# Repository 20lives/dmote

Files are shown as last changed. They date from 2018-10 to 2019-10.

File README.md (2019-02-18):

## The Dactyl-ManuForm keyboard: Opposable Thumb Edition

This, the DMOTE, is a fork of the
[Dactyl-ManuForm](https://github.com/tshort/dactyl-keyboard), a parametrized,
split-hand, concave, columnar, ergonomic keyboard. In this fork, the thumb
cluster has been modified to minimize shearing forces.

Image of the second working DMOTE (http://viktor.eikman.se/article/the-dmote/)

Parameters have been moved out of the application code itself, into separate
files that are safe and easy to edit. Use them to change:

- Switch type: ALPS or MX.
- Size and shape.
    - Row and column curvature and tilt (tenting).
    - Exceptions at any level, down to the position of individual keys.
- Minor features like LED strips and wrist rests.

For documentation see [doc/](doc/).

### License

Copyright © 2015-2019 Matthew Adereth, Tom Short, Viktor Eikman et al.

The source code for generating the models (everything excluding the [things/](things/) and [resources/](resources/) directories) is distributed under the [GNU AFFERO GENERAL PUBLIC LICENSE Version 3](LICENSE). The generated models and PCB designs are distributed under the [Creative Commons Attribution-NonCommercial-ShareAlike License Version 3.0](LICENSE-models).

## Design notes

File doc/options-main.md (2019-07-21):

# General configuration options

Each heading in this document represents a recognized configuration key in the main body of a YAML file for a DMOTE variant. Other documents cover special sections of this one in more detail.

## Parameter `split`

If `true`, build two versions of the case: One for the right hand and a mirror image for the left hand. Threaded holes and other chiral components of the case are exempted from mirroring.

## Section `keys`

Keys, that is keycaps and electrical switches, are not the main focus of this application, but they influence the shape of the case.

### Parameter `preview`

If `true`, include models of the keycaps in place on the keyboard. This is intended for illustration as you work on a design, not for printing.

### Parameter `styles`

Here you name all the types of keys on the keyboard. For each type, describe the properties of the style using the parameters of the [`dmote-keycap`](https://github.com/veikman/dmote-keycap) library, documented in that project. The names of the styles are then used elsewhere, as described [here](options-nested.md).

Key styles determine the size of key mounting plates on the keyboard and what kind of holes are cut into those plates for the switches to fit into. Negative space is also reserved above the plate, for the movement of the keycap: A function of switch height, switch travel, and keycap shape. In addition, if the keyboard is curved, key styles help determine the spacing between key mounts.

## Special section `key-clusters`

This section describes the general size, shape and position of the clusters of keys on the keyboard, each in its own subsection. It is documented in detail [here](options-clusters.md).

## Section `by-key`

This section repeats. Each level of settings inside it is more specific to a smaller part of the keyboard, eventually reaching the level of individual keys. It’s all documented [here](options-nested.md).

### Special recurring section `parameters`

Default values at the global level.

### Special section `clusters` ← overrides go in here

Starting here, you gradually descend from the global level toward the key level.

## Parameter `secondaries`

A map where each item provides a name for a position in space. Such positions exist in relation to other named features of the keyboard and can themselves be used as named features: Typically as supplementary targets for `tweaks`, which are defined below.

An example:

```secondaries:
  s0:
    anchor: f0
    corner: NNE
    segment: 3
    offset: [0, 0, 10]
```
This example gives the name `s0` to a point 10 mm above a key or some other feature named `f0`, which must be defined elsewhere.

A `corner` and `segment` are useful mainly with key aliases. An `offset` is applied late, i.e. in the overall coordinate system, following any transformations inherent to the anchor.

## Section `case`

Much of the keyboard case is generated from the `wall` parameters described [here](options-nested.md). This section deals with lesser features of the case.

### Parameter `key-mount-thickness`

The thickness in mm of each switch key mounting plate.

### Parameter `key-mount-corner-margin`

The thickness in mm of an imaginary “post” at each corner of each key mount. Copies of such posts project from the key mounts to form the main walls of the case.

`key-mount-thickness` is similarly the height of each post.

### Parameter `web-thickness`

The thickness in mm of the webbing between switch key mounting plates, and of the rear housing’s walls and roof.

### Section `rear-housing`

The furthest row of a key cluster can be extended into a rear housing for the MCU and various other features.

#### Parameter `include`

If `true`, add a rear housing. Please arrange case walls so as not to interfere, by removing them along the far side of the last row of key mounts in the indicated cluster.

#### Parameter `wall-thickness`

The horizontal thickness in mm of the walls.

#### Parameter `roof-thickness`

The vertical thickness in mm of the flat top.

#### Section `position`

Where to put the rear housing. By default, it sits all along the far side of the `main` cluster but has no depth.

##### Parameter `cluster`

The key cluster at which to anchor the housing.

##### Section `offsets`

Modifiers for where to put the four sides of the roof. All are in mm.

###### Parameter `north`

The extent of the roof on the y axis; its horizontal depth.

###### Parameter `west`

The extent on the x axis past the first key in the row.

###### Parameter `east`

The extent on the x axis past the last key in the row.

###### Parameter `south`

The horizontal distance in mm, on the y axis, between the furthest key in the row and the roof of the rear housing.

#### Parameter `height`

The height in mm of the roof, over the floor.

#### Section `fasteners`

Threaded bolts can run through the roof of the rear housing, making it a hardpoint for attachments like a stabilizer to connect the two halves of a split keyboard.

##### Parameter `diameter`

The ISO metric diameter of each fastener.

##### Parameter `bosses`

If `true`, add nut bosses to the ceiling of the rear housing for each fastener. Space permitting, these bosses will have some play on the north-south axis, to permit adjustment of the angle of the keyboard halves under a stabilizer.

##### Section `west`

A fastener on the inward-facing end of the rear housing.

###### Parameter `include`

If `true`, include this fastener.

###### Parameter `offset`

A one-dimensional offset in mm from the inward edge of the rear housing to the fastener. You probably want a negative number if any.

##### Section `east`

A fastener on the outward-facing end of the rear housing. All parameters are analogous to those for `west`.

###### Parameter `include`

###### Parameter `offset`

### Section `back-plate`

Given that independent movement of each half of a split keyboard is not useful, each half can include a mounting plate for a stabilizing ‘beam’. That is a straight piece of wood, aluminium, rigid plastic etc. to connect the two halves mechanically and possibly carry the wire that connects them electrically.

This option is similar to rear housing, but the back plate block provides no interior space for an MCU etc. It is solid, with holes for threaded fasteners including the option of nut bosses. Its footprint is not part of a `bottom-plate`.

#### Parameter `include`

If `true`, include a back plate block. This is not contingent upon `split`.

#### Parameter `beam-height`

The nominal vertical extent of the back plate in mm. Because the plate is bottom-hulled to the floor, the effect of this setting is on the area of the plate above its holes.

#### Section `fasteners`

Two threaded bolts run through the back plate.

##### Parameter `diameter`

The ISO metric diameter of each fastener.

##### Parameter `distance`

The horizontal distance between the fasteners.

##### Parameter `bosses`

If `true`, cut nut bosses into the inside wall of the block.

#### Section `position`

The block is positioned in relation to a named feature.

##### Parameter `anchor`

The name of a feature where the block will attach.

##### Parameter `offset`

An offset in mm from the named feature to the middle of the base of the back-plate block.

### Section `bottom-plate`

A bottom plate can be added to close the case. This is useful mainly to simplify transportation.

#### Overview

The bottom plate is largely two-dimensional. The application builds most of it from a set of polygons, trying to match the perimeter of the case at the ground level (i.e. z = 0).

Specifically, there is one polygon per key cluster, limited to `full` wall edges, one polygon for the rear housing, and one set of polygons for each of the first-level case `tweaks` that use `at-ground`, ignoring chunk size and almost ignoring tweaks nested within lists of tweaks.

This methodology is mentioned here because its results are not perfect. Pending future features in OpenSCAD, a future version may be based on a more exact projection of the case, but as of 2018, such a projection is hollow and cannot be convex-hulled without escaping the case, unless your case is convex to start with.

For this reason, while the polygons fill the interior, the perimeter of the bottom plate is extended by key walls and case `tweaks` as they would appear at the height of the bottom plate. Even this brutality may be inadequate. If you require a more exact match, do a projection of the case without a bottom plate, save it as DXF/SVG etc. and post-process that file to fill the interior gap.

#### Parameter `include`

If `true`, include a bottom plate for the case.

#### Parameter `preview`

Preview mode. If `true`, put a model of the plate in the same file as the case it closes. Not for printing.

#### Parameter `combine`

If `true`, combine wrist rests for the case and the bottom plate into a single model, when both are enabled. This is typically used with the `solid` style of wrest rest.

#### Parameter `thickness`

The thickness (i.e. height) in mm of all bottom plates you choose to include. This covers plates for the case and for the wrist rest.

The case will not be raised to compensate for this. Instead, the height of the bottom plate will be removed from the bottom of the main model so that it does not extend to z = 0.

#### Section `installation`

How your bottom plate is attached to the rest of your case.

##### Parameter `style`

The general means of installation. All currently available styles use threaded fasteners with countersunk heads. The styles differ only in how these fasteners attach to the case.

One of:

- `threads`: Threaded holes in the case.
- `inserts`: Unthreaded holes for threaded heat-set inserts.

##### Parameter `thickness`

The thickness in mm of each wall of the anchor points.

##### Section `inserts`

Properties of heat-set inserts for the `inserts` style.

###### Parameter `length`

The length in mm of each insert.

###### Section `diameter`

It is assumed that, as in Tom Short’s Dactyl-ManuForm, the inserts are largely cylindrical but vary in diameter across their length.

###### Parameter `top` at level 7

Top diameter in m.

###### Parameter `bottom` at level 7

Bottom diameter in mm. This needs to be at least as large as the top diameter since the mounts for the inserts only open from the bottom.

##### Section `fasteners`

The type and positions of the threaded fasteners used to secure each bottom plate.

###### Parameter `diameter`

The ISO metric diameter of each fastener.

###### Parameter `length`

The length in mm of each fastener. In the `threads` style, this refers to the part of the screw that is itself threaded: It excludes the head.

###### Parameter `positions`

A list of places where threaded fasteners will connect the bottom plate to the rest of the case.

### Section `leds`

Support for light-emitting diodes in the case walls.

#### Parameter `include`

If `true`, cut slots for LEDs out of the case wall, facing the space between the two halves.

#### Section `position`

Where to attach the LED strip.

##### Parameter `cluster`

The key cluster at which to anchor the strip.

#### Parameter `amount`

The number of LEDs.

#### Parameter `housing-size`

The length of the side on a square profile used to create negative space for the housings on a LED strip. This assumes the housings are squarish, as on a WS2818.

The negative space is not supposed to penetrate the wall, just make it easier to hold the LED strip in place with tape, and direct its light. With that in mind, feel free to exaggerate by 10%.

#### Parameter `emitter-diameter`

The diameter of a round hole for the light of an LED.

#### Parameter `interval`

The distance between LEDs on the strip. You may want to apply a setting slightly shorter than the real distance, since the algorithm carving the holes does not account for wall curvature.

### Parameter `tweaks`

Additional shapes. This is usually needed to bridge gaps between the walls of the key clusters. The expected value here is an arbitrarily nested structure starting with a map of names to lists.

The names at the top level are arbitrary but should be distinct and descriptive. Their only technical significance lies in the fact that when you combine multiple configuration files, a later tweak will override a previous tweak if and only if they share the same name.

Below the names, each item in each list can follow one of the following patterns:

- A leaf node. This is a tuple of 1 to 4 elements specified below.
- A map, representing an instruction to combine nested items in a specific way.
- A list of any combination of the other two types. This type exists at the second level from the top and as the immediate child of each map node.

Each leaf node identifies a particular named feature of the keyboard. It’s usually a set of corner posts on a named (aliased) key mount. These are identical to the posts used to build the walls, but this section gives you greater freedom in how to combine them. The elements of a leaf are, in order:

1. Mandatory: The name of a feature, such as a key alias.
2. Optional: A corner ID, such as `NNE` for north by north-east. If this is omitted, i.e. if only the mandatory element is given, the tweak will use the middle of the named feature.
3. Optional: A starting wall segment ID, which is an integer from 0 to 4 inclusive. If this is omitted, but a corner is named, the default value is 0.
4. Optional: A second wall segment ID. If this is provided, the leaf will represent the convex hull of the two indicated segments plus all segments between them. If this is omitted, only one wall post will be placed.

By default, a map node will create a convex hull around its child nodes. However, this behaviour can be modified. The following keys are recognized:

- `at-ground`: If `true`, child nodes will be extended vertically down to the ground plane, as with a `full` wall. The default value for this key is `false`. See also: `bottom-plate`.
- `above-ground`: If `true`, child nodes will be visible as part of the case. The default value for this key is `true`.
- `chunk-size`: Any integer greater than 1. If this is set, child nodes will not share a single convex hull. Instead, there will be a sequence of smaller hulls, each encompassing this many items.
- `highlight`: If `true`, render the node in OpenSCAD’s highlighting style. This is convenient while you work.
- `hull-around`: The list of child nodes. Required.

In the following example, `A` and `B` are key aliases that would be defined elsewhere. The example is interpreted to mean that a plate should be created stretching from the south-by-southeast corner of `A` to the north-by-northeast corner of `B`. Due to `chunk-size` 2, that first plate will be joined, not hulled, with a second plate from `B` back to a different corner of `A`, with a longer stretch of (all) wall segments down the corner of `A`.

```case:
  tweaks:
    bridge-between-A-and-B:
      - chunk-size: 2
        hull-around:
        - [A, SSE]
        - [B, NNE]
        - [A, SSW, 0, 4]
```

### Section `foot-plates`

Optional flat surfaces at ground level for adding silicone rubber feet or cork strips etc. to the bottom of the keyboard to increase friction and/or improve feel, sound and ground clearance.

#### Parameter `include`

If `true`, include foot plates.

#### Parameter `height`

The height in mm of each mounting plate.

#### Parameter `polygons`

A list describing the horizontal shape, size and position of each mounting plate as a polygon.

## Section `mcu`

This is short for ”micro-controller unit”. Each half has one.

### Parameter `include`

If `true`, build support for the MCU PCBA.

### Parameter `preview`

If `true`, render a visualization of the MCU PCBA. For use in development.

### Parameter `type`

A symbolic name for a commercial product. Currently, only `promicro` is supported, referring to any MCU PCBA with the dimensions of a SparkFun Pro Micro, including That-Canadian’s Elite-C.

### Parameter `margin`

A general measurement in mm of extra space around each part of the PCBA, including PCB and USB connector. This is applied to DMOTE components meant to hold the PCBA in place, accounting for printing inaccuracy as well as inaccuracies in manufacturing the PCBA.

### Section `position`

Where to place the MCU PCBA.

#### Parameter `prefer-rear-housing`

If `true` and `rear-housing` is included, place the PCBA in relation to the rear housing. Otherwise, place the PCBA in relation to a named feature identified by `anchor`.

#### Parameter `anchor`

The name of a key at which to place the PCBA if `prefer-rear-housing` is `false` or rear housing is not included.

#### Parameter `corner`

A code for a corner of the `anchor` feature. This determines both the location and facing of the PCBA.

#### Parameter `offset`

A 3D offset in mm, measuring from the `corner`.

#### Parameter `rotation`

A vector of 3 angles in radians. This parameter governs the rotation of the PCBA around its anchor point in the front. You would not normally need this for the PCBA.

### Section `support`

The support structure that holds the MCU PCBA in place.

#### Parameter `style`

The style of the support. Available styles are:

- `lock`: A separate physical object that is bolted in place over the MCU. This style is appropriate only with a rear housing, and then only when the PCB aligns with a long wall of that housing. It has the advantage that it can hug the connector on the PCB tightly, thus preventing a fragile surface-mounted connector from breaking off.
- `stop`: A gripper that holds the PCBA in place at its rear end. This gripper, in turn, is held up by key mount webbing and is thus integral to the keyboard, not printed separately like the lock. This style does not require rear housing.

#### Parameter `preview`

If `true`, render a visualization of the support in place. This applies only to those parts of the support that are not part of the case model.

#### Parameter `height-factor`

A multiplier for the width of the PCB, producing the height of the support actually touching the PCB.

#### Parameter `lateral-spacing`

A lateral 1D offset in mm. With rear housing, this creates space between the rear housing itself and the back of the PCB’s through-holes, so it should be roughly matched to the length of wire overshoot. Without rear housing, it isn’t so useful but it does work analogously.

#### Section `lock`

Parameters relevant only with a `lock`-style support.

##### Section `fastener`

A threaded bolt connects the lock to the case.

###### Parameter `style`

A style of bolt head (cap) supported by `scad-tarmi`.

###### Parameter `diameter`

The ISO metric diameter of the fastener.

##### Section `socket`

A housing around the USB connector on the MCU PCBA.

###### Parameter `thickness`

The wall thickness of the socket.

##### Section `bolt`

The part of a `lock`-style support that does not print with the keyboard case. This bolt, named by analogy with a lock, is not to be confused with the threaded fastener (also a bolt) holding it in place.

###### Parameter `clearance`

The distance of the bolt from the populated side of the PCB. This distance should be slightly greater than the height of the tallest component on the PCB.

###### Parameter `overshoot`

The distance across which the bolt will touch the PCB at the mount end. Take care that this distance is free of components on the PCB.

###### Parameter `mount-length`

The length of the base containing a threaded channel used to secure the bolt over the MCU. This is in addition to `overshoot` and goes in the opposite direction, away from the PCB.

###### Parameter `mount-thickness`

The thickness of the mount. This should have some rough correspondence to the threaded portion of your fastener, which should not have a shank.

#### Section `stop`

Parameters relevant only with a `stop`-style support.

##### Parameter `anchor`

The name of a key where a stop will start to attach itself.

##### Parameter `direction`

A direction in the matrix from the named key. The stop will attach to a hull of four neighbouring key mount corners in this direction.

##### Section `gripper`

The shape of the part that grips the PCB.

###### Parameter `notch-depth`

The horizontal depth of the notch in the gripper that holds the PCB. The larger this number, the more flexible the case has to be to allow assembly.

Note that while this is similar in effect to `lock`-style `overshoot`, it is a separate parameter because of the flexion limit.

###### Parameter `total-depth`

The horizontal depth of the gripper as a whole in line with the PCB.

###### Parameter `grip-width`

The width of a protrusion on each side of the notch.

## Section `connection`

There must be a signalling connection between the two halves of a split keyboard.

### Parameter `include`

If `true`, inclue a “metasocket”, i.e. physical support for a socket where you plug in a cable that will, in turn, provide the signalling connection between the two halves.

### Parameter `socket-size`

The size in mm of a hole in the case, for the female to fit into. For example, the female might be a type 616E socket for a (male) 4P4C “RJ9” plug, in which case the metasocket has to fit around the entire 616E.

This parameter assumes a cuboid socket. For a socket of a different shape, get as close as possible, then make your own adapter and/or widen the metasocket with a soldering iron or similar tools.

### Parameter `socket-thickness`

The thickness in mm of the roof, walls and floor of the metasocket, i.e. around the hole in the case.

### Section `position`

Where to place the socket. Equivalent to `mcu` → `position`.

#### Parameter `prefer-rear-housing`

#### Parameter `anchor`

#### Parameter `corner`

#### Parameter `raise`

If `true`, and the socket is being placed in relation to the rear housing, put it directly under the ceiling, instead of directly over the floor.

#### Parameter `offset`

#### Parameter `rotation`

## Section `wrist-rest`

An optional extension to support the user’s wrist.

### Parameter `include`

If `true`, include a wrist rest with the keyboard.

### Parameter `style`

The style of the wrist rest. Available styles are:

- `threaded`: threaded fasteners connect the case and wrist rest.
- `solid`: the case and wrist rest are joined together by `tweaks` as a single piece of plastic.

### Parameter `preview`

Preview mode. If `true`, this puts a model of the wrist rest in the same OpenSCAD file as the case. That model is simplified, intended for gauging distance, not for printing.

### Section `position`

The wrist rest is positioned in relation to a named feature.

#### Parameter `anchor`

The name of a feature where the wrist rest will attach. The vertical component of its position will be ignored.

#### Parameter `corner`

A corner of the feature named in `anchor`.

#### Parameter `offset`

An offset in mm from the feature named in `anchor`.

### Parameter `plinth-height`

The average height of the plastic plinth in mm, at its upper lip.

### Section `shape`

The wrist rest needs to fit the user’s hand.

#### Section `spline`

The horizontal outline of the wrist rest is a closed spline.

##### Parameter `main-points`

A list of nameable points, in clockwise order. The spline will pass through all of these and then return to the first one. Each point can have two properties:

- Mandatory: `position`. A pair of coordinates, in mm, relative to other points in the list.
- Optional: `alias`. A name given to the specific point, for the purpose of placing yet more things in relation to it.

##### Parameter `resolution`

The amount of vertices per main point. The default is 1. If 1, only the main points themselves will be used, giving you full control. A higher number gives you smoother curves.

If you want the closing part of the curve to look smooth in high resolution, position your main points carefully.

Resolution parameters, including this one, can be disabled in the main `resolution` section.

#### Section `lip`

The lip is the uppermost part of the plinth, lining and supporting the edge of the pad. Its dimensions are described here in mm away from the pad.

##### Parameter `height`

The vertical extent of the lip.

##### Parameter `width`

The horizontal width of the lip at its top.

##### Parameter `inset`

The difference in width between the top and bottom of the lip. A small negative value will make the lip thicker at the bottom. This is recommended for fitting a silicone mould.

#### Section `pad`

The top of the wrist rest should be printed or cast in a soft material, such as silicone rubber.

##### Section `surface`

The upper surface of the pad, which will be in direct contact with the user’s palm or wrist.

###### Section `edge`

The edge of the pad can be rounded.

###### Parameter `inset` at level 7

The horizontal extent of softening. This cannot be more than half the width of the outline, as determined by `main-points`, at its narrowest part.

###### Parameter `resolution` at level 7

The number of faces on the edge between horizontal points.

Resolution parameters, including this one, can be disabled in the main `resolution` section.

###### Section `heightmap`

The surface can optionally be modified by the [`surface()` function](https://en.wikibooks.org/wiki/OpenSCAD_User_Manual/Other_Language_Features#Surface), which requires a heightmap file.

###### Parameter `include` at level 7

If `true`, use a heightmap. The map will intersect the basic pad polyhedron.

###### Parameter `filepath` at level 7

The file identified here should contain a heightmap in a format OpenSCAD can understand. The path should also be resolvable by OpenSCAD.

##### Section `height`

The piece of rubber extends a certain distance up into the air and down into the plinth. All measurements in mm.

###### Parameter `surface-range`

The vertical range of the upper surface. Whatever values are in a heightmap will be normalized to this scale.

###### Parameter `lip-to-surface`

The part of the rubber pad between the top of the lip and the point where the heightmap comes into effect. This is useful if your heightmap itself has very low values at the edges, such that moulding and casting it without a base would be difficult.

###### Parameter `below-lip`

The depth of the rubber wrist support, measured from the top of the lip, going down into the plinth. This part of the pad just keeps it in place.

### Section `rotation`

The wrist rest can be rotated to align its pad with the user’s palm.

#### Parameter `pitch`

Tait-Bryan pitch.

#### Parameter `roll`

Tait-Bryan roll.

### Special section `mounts`

A list of mounts for threaded fasteners. Each such mount will include at least one cuboid block for at least one screw that connects the wrist rest to the case. This section is used only with the `threaded` style of wrist rest.

### Section `sprues`

Holes in the bottom of the plinth. You pour liquid rubber through these holes when you make the rubber pad. Sprues are optional, but the general recommendation is to have two of them if you’re going to be casting your own pads. That way, air can escape even if you accidentally block one sprue with a low-viscosity silicone.

#### Parameter `include`

If `true`, include sprues.

#### Parameter `inset`

The horizontal distance between the perimeter of the wrist rest and the default position of each sprue.

#### Parameter `diameter`

The diameter of each sprue.

#### Parameter `positions`

The positions of all sprues. This is a list where each item needs an `anchor` naming a main point in the spline. You can add an optional two-dimensional `offset`.

### Section `bottom-plate`

The equivalent of the case `bottom-plate` parameter. If included, a bottom plate for a wrist rest uses the `thickness` configured for the bottom of the case.

Bottom plates for the wrist rests have no ESDS electronics to protect but serve other purposes: Covering nut pockets, silicone mould-pour cavities, and plaster or other dense material poured into plinths printed without a bottom shell.

#### Parameter `include`

Whether to include a bottom plate for each wrist rest.

#### Parameter `inset`

The horizontal distance between the perimeter of the wrist rest and the default position of each threaded fastener connecting it to its bottom plate.

#### Parameter `fastener-positions`

The positions of threaded fasteners used to attach the bottom plate to its wrist rest. The syntax of this parameter is precisely the same as for the case’s bottom-plate fasteners. Corners are ignored and the starting position is inset from the perimeter of the wrist rest by the `inset` parameter above, before any offset stated here is applied.

Other properties of these fasteners are determined by settings for the case.

### Parameter `mould-thickness`

The thickness in mm of the walls and floor of the mould to be used for casting the rubber pad.

## Section `resolution`

Settings for the amount of detail on curved surfaces. More specific resolution parameters are available in other sections.

### Parameter `include`

If `true`, apply resolution parameters found throughout the configuration. Otherwise, use defaults built into this application, its libraries and OpenSCAD. The defaults are generally conservative, providing quick renders for previews.

### Parameter `minimum-face-size`

File-wide OpenSCAD minimum face size in mm.

## Section `dfm`

Settings for design for manufacturability (DFM).

### Parameter `error-general`

A measurement in mm of errors introduced to negative space in the xy plane by slicer software and the printer you will use.

The default value is zero. An appropriate value for a typical slicer and FDM printer with a 0.5 mm nozzle would be about -0.5 mm.

This application will try to compensate for the error, though only for certain sensitive inserts, not for the case as a whole.

### Section `keycaps`

Measurements of error, in mm, for parts of keycap models. This is separate from `error-general` because it’s especially important to have a tight fit between switch sliders and cap stems, and the size of these details is usually comparable to an FDM printer nozzle.

If you will not be printing caps, ignore this section.

#### Parameter `error-stem-positive`

Error on the positive components of stems on keycaps, such as the entire stem on an ALPS-compatible cap.

#### Parameter `error-stem-negative`

Error on the negative components of stems on keycaps, such as the cross on an MX-compatible cap.

### Section `bottom-plate`

DFM for bottom plates.

#### Parameter `fastener-plate-offset`

A vertical offset in mm for the placement of screw holes in bottom plates. Without a slight negative offset, slicers will tend to make the holes too wide for screw heads to grip the plate securely.

Notice this will not affect how screw holes are cut into the case.

## Section `mask`

A box limits the entire shape, cutting off any projecting by-products of the algorithms. By resizing and moving this box, you can select a subsection for printing. You might want this while you are printing prototypes for a new style of switch, MCU support etc.

### Parameter `size`

The size of the mask in mm. By default, `[1000, 1000, 1000]`.

### Parameter `center`

The position of the center point of the mask. By default, `[0, 0, 500]`, which is supposed to mask out everything below ground level. If you include bottom plates, their thickness will automatically affect the placement of the mask beyond what you specify here.

⸻

This document was generated from the application CLI.

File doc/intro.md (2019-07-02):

# Introduction to the DMOTE

Here’s how to use this code repository to build a keyboard case.
For a still-more general introduction to the larger project, see
[this](http://viktor.eikman.se/article/the-dmote/).

## From code to print

This repository is source code for a Clojure application. Clojure runs on
[the JVM](https://en.wikipedia.org/wiki/Java_(software_platform)). The
application produces an [OpenSCAD](http://www.openscad.org/) program which,
in turn, can be rendered to a portable geometric description like
[STL](https://en.wikipedia.org/wiki/STL_(file_format)). STL can be
[sliced](https://en.wikipedia.org/wiki/Slicer_(3D_printing)) to
[G-code](https://en.wikipedia.org/wiki/G-code) and the G-code can
steer a 3D printer.

OpenSCAD can represent the model visually, but there is no step in this process
where you point and click with a mouse to change the design. The shape of the
keyboard is determined by your written parameters to the Clojure application.

Roughly, the build chain looks like this:

> parameters through this app (compiled) → preview → rendering → slicing → printing

Equivalently, in terms of typical file name endings:

> .yaml through .clj (or .jar) → .scad → .stl → .gcode → tangible keyboard

If this repository includes STL files you will find them in the
[`things/stl`](../things/) directory. They should be ready to print. Otherwise,
here’s how to make your own.

### Setting up the build environment

* Install the [Clojure runtime](https://clojure.org)
* Install the [Leiningen project manager](http://leiningen.org/)
* Optional: Install [GNU make](https://www.gnu.org/software/make/)
* Install [OpenSCAD](http://www.openscad.org/)

On Debian GNU+Linux, the first three are accomplished with
`apt install clojure leiningen make`.

The necessary Clojure libraries will be pulled in by a `lein run`.

### Finding bundled configurations

The Clojure application combines configuration details from zero or more
[YAML](https://en.wikipedia.org/wiki/YAML) files. There are examples in
[`config`](config/). These files have a nested structure
[documented here](options-main.md).

The files are used when you pass them to the application, not automatically.
The ones you name are gently combined into a single master configuration. In
this process, files named later take precedence over those names earlier, in
case of direct conflicts.

### Producing OpenSCAD and STL files

* To produce OpenSCAD files for the default configuration, run `make`.
  * If you do not have Make, or if you want more control, run `lein run` with
    the arguments you see prepared in the makefile. For example,
    `lein run -c config/base.yaml -c config/dmote/base.yaml` will
    build a basic DMOTE, with the same results as `make`, just
    without an optional compilation step that speeds up each iteration.
* In OpenSCAD, open one of the `things/scad/*.scad` files for a preview.
  * To render a complex model in OpenSCAD you may need to go to Edit >>
    Preferences >> Advanced and raise the ceiling for when to “Turn off
    rendering”.
* When satisfied, render to STL by calling the Clojure application with the
  `--render` flag in addition to previous flags, i.e. those you typed yourself
  or got through Make. You can also render directly from OpenSCAD.

If you do have Make and you want to weave in more configuration files, you can
put more YAML paths on the command line or name an intermediate Make target, or
do both. However, this is not what Make is for, so you will need to finish with
a named target that actually calls the application, as in `make vis
dmote_62key`, where `dmote_62key` is the (otherwise implicit) default target.

There are [other ways to evaluate](http://stackoverflow.com/a/28213489) the
Clojure code, including the bundled `transpile.sh` shell script, which will
tail your changes with `inotify` if you have that.

## Customization

You probably want to customize the design for your own hands. You won’t need
to do any coding if all you want is a personal fit or additional keys.

You can change the bundled YAML files if you like. However, it is generally
easier to add your own files, maintaining them separately from the DMOTE
repository. That way, they will be safe if you upgrade the application with a
`git pull`.

Remember to put your own file(s) last in your list of arguments to the
application, to get the most power. For example, to override all the ALPS-style
key mounts with MX-style mounts on a DMOTE, run `lein run -c config/base.yaml
-c config/dmote/base.yaml -c config/dmote/mx.yaml`.

#### Nomenclature: Finding north

The parameter files and the code use the cardinal directions of the compass
to describe directions in the space of the keyboard model. To understand these,
imagine having (the right-hand side of) the keyboard in front of you, as you
would use it, while you face true north.

“North” in configuration thus refers to the direction away from the user: the
far side. “South” is the direction toward the user: the near side.

“West” and “east” vary on each half of a split keyboard because the left-hand
side is a mirror image of the right-hand side. The right-hand side is primary
for the purposes of nomenclature. On either half, the west is inward, toward
the space between the two halves of the keyboard. The east is outward, away
from the other half of the keyboard. If you are not building a split keyboard,
think of your case as you would the right-hand side: The west is on your left
and the east is on your right.

In Euclidean space, the x axis goes from west to east, the y axis from
south to north, and the z axis from earth to sky.

### Deeper changes

If you find that you cannot get what you want just by changing the parameters,
you need to edit the source code. If you are not familiar with OpenSCAD, start
by experimenting with its native format, writing `.scad` files from scratch.
Then consider starting in `src/dactyl_keyboard/sandbox.clj` to get familiar
with `scad-clj`. It writes OpenSCAD code for you with helpful abstractions.

If you want your changes to the source code to be merged upstream, please do
not remove or break existing features. There are already several `include` and
`style` parameters designed to support a variety of mutually incompatible
styles in the code base. Add yours instead of simply repurposing functions,
and test to make sure you have not damaged other styles.

## Printing tips

For printing prototypes and any printing with PLA-like materials that stiffen
quickly, build support from the base plate only. This simplifies the process
of removing the supports.

For accuracy problems, especially with threaded fasteners, consider tweaking
the DFM settings [documented here](options-main.md), particularly the
`error-general` parameter.

### Bottom plates

If you are using threaded fasteners to connect bottom plates directly to the
case (the `threads` style), please note that common FDM printers usually won’t
print threaded holes smaller than M3 with useful accuracy. M4 is a safer bet.

If you are having trouble with the fit and neither DFM settings nor larger
fasteners are helping, consider a greater `thickness` for the anchor points,
along with slicer settings that give you thinner walls and less infill. This
should give you a more yielding threaded hole, decreasing the risk of a
delaminating crack, but increasing the risk of threads deforming over time.

In any case you may want to use `foot-plates` to provide additional support for
the anchor points.

### Wrist rests

If you are including wrist rests, consider printing the plinths without a
bottom plate and with sparse or gradual infill. This makes it easy to pour
plaster or some other dense material into the plinths to add mass.

## After printing

Instructions specific to the DMOTE have yet to be written for hand-wiring the
switches with diodes and installing embedded microcontrollers. To get started
with that stuff, please refer to the original instructions for the
Dactyl-ManuForm or the Dactyl, or contact the maintainer of the fork you
are printing.

As for microcontroller firmware, QMK works great. In that project, the DMOTE
is filed as a version of the Dactyl-ManuForm
[here](https://github.com/qmk/qmk_firmware/tree/master/keyboards/handwired/dactyl_manuform/dmote).

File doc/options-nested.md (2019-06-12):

# Nestable configuration options

This document describes all those settings which can be made at any level of specificity, from the entire keyboard down to an individual key. These settings all go under `by-key` in a YAML file.

## Conceptual overview

Specificity is accomplished by nesting. The following levels of specificity are currently available. Each one branches out, containing the next:

- The global level, directly under `by-key` (cf. the [main document](options-main.md)).
- The key cluster level, at `by-key` → `clusters` → your cluster.
- The column level, nested still further under your cluster → `columns` → column index.
- The row level, nested at the bottom, under column index → `rows` → row index.

A setting at the row level will only affect keys in the specific cluster and column selected along the way, i.e. only one key per row. Therefore, the row level is effectively the key level.

At each level, two subsections are permitted: `parameters`, where you put the settings themselves, and a section for the next level of nesting: `clusters`, then `columns`, then `rows`. More specific settings take precedence.

In the following hypothetical example, the parameter `P`, which is not really supported, is defined three times: Once at the global level and twice at the row (key) level.

```by-key:
  parameters:
    P: true
  clusters:
    C:
      columns:
        "1":
          rows:
            first:
              parameters:
                P: false
            "3":
              parameters:
                P: false
```

In this example, `P` will have the value “true” for all keys except two on each half of the keyboard. On the right-hand side, `P` will be false for the key closest to the user (“first” row) in the second column from the left (column “1”) in a cluster of keys here named `C`. `P` will also be false for the fourth key from the user (row “3”) in the same column.

Columns and rows are indexed by their ordinal integers or the words “first” or “last”, which take priority.

WARNING: Due to a peculiarity of the YAML parser, take care to quote your numeric column and row indices as strings. This is why there are quotation marks around column index 1 and row index 3 in the example.

## Section `layout`

Settings for how to place keys.

### Section `matrix`

Roughly how keys are spaced out to form a matrix.

#### Section `neutral`

The neutral point in a column or row is where any progressive curvature both starts and has no effect.

##### Parameter `column`

An integer column ID.

##### Parameter `row`

An integer row ID.

#### Section `separation`

Tweaks to control the systematic separation of keys. The parameters in this section will be multiplied by the difference between each affected key’s coordinates and the neutral column and row.

##### Parameter `column`

A distance in mm.

##### Parameter `row`

A distance in mm.

### Section `pitch`

Tait-Bryan pitch, meaning the rotation of keys around the x axis.

#### Parameter `base`

An angle in radians. Set at a high level, this controls the general front-to-back incline of a key cluster.

#### Parameter `intrinsic`

An angle in radians. Intrinsic pitching occurs early in key placement. It is typically intended to produce a tactile break between two rows of keys, as in the typewriter-like terracing common on flat keyboards with OEM-profile or similarly angled caps.

The term “intrinsic” is used here because the key spins roughly around its own center. The term should not be confused with intrinsic rotations in the sense that each step is performed on a coordinate system resulting from previous operations.

#### Parameter `progressive`

An angle in radians. This progressive pitch factor bends columns lengthwise. If set to zero, columns are flat.

### Section `roll`

Tait-Bryan roll, meaning the rotation of keys around the y axis.

#### Parameter `base`

An angle in radians. This is the “tenting” angle. Applied to your main cluster, it controls the overall left-to-right tilt of each half of the keyboard.

#### Parameter `intrinsic`

An angle in radians, analogous to intrinsic pitching. Where more than one column of keys is devoted to a single finger at the edge of the keyboard, this can help make the edge column easier to reach, reducing the need to bend the finger (or thumb) sideways.

#### Parameter `progressive`

An angle in radians. This progressive roll factor bends rows lengthwise, which also gives the columns a lateral curvature.

### Section `yaw`

Tait-Bryan yaw, meaning the rotation of keys around the z axis.

#### Parameter `base`

An angle in radians. Applied to your main key cluster, this serves the purpose of allowing the user to keep their wrists straight even if the two halves of the keyboard are closer together than the user’s shoulders.

#### Parameter `intrinsic`

An angle in radians, analogous to intrinsic pitching.

### Section `translation`

Translation in the geometric sense, displacing keys in relation to each other. Depending on when this translation takes places, it may have a a cascading effect on other aspects of key placement. All measurements are three-dimensional vectors in mm.

#### Parameter `early`

”Early” translation happens before other operations in key placement and therefore has the biggest knock-on effects.

#### Parameter `mid`

This happens after columns are styled but before base pitch and roll. As such it is a good place to adjust whole columns for relative finger length.

#### Parameter `late`

“Late” translation is the last step in key placement and therefore interacts very little with other steps.

## Parameter `key-style`

The name of a key style defined in the [global](options-main.md) `keys` section. The default value for this setting is the name `default`.

## Section `channel`

Above each switch mount, there is a channel of negative space for the user’s finger and the keycap to move inside. This is only useful in those cases where nearby walls or webbing between mounts on the keyboard would otherwise obstruct movement.

### Parameter `height`

The height in mm of the negative space, starting from the bottom edge of each keycap in its pressed (active) state.

### Parameter `top-width`

The width in mm of the negative space at its top. Its width at the bottom is defined by keycap geometry.

### Parameter `margin`

The width in mm of extra negative space around the edges of a keycap, on all sides. This is applied before the `error-general` DFM compensator.

## Section `wall`

The walls of the keyboard case support the key mounts and protect the electronics. They are generated by an algorithm that walks around each key cluster.

This section determines the shape of the case wall, specifically the skirt around each key mount along the edges of the board. These skirts are made up of convex hulls wrapping sets of corner posts.

There is one corner post at each actual corner of every key mount. More posts are displaced from it, going down the sides. Their placement is affected by the way the key mounts are rotated etc.

### Parameter `thickness`

A distance in mm.

This is actually the distance between some pairs of corner posts (cf. `key-mount-corner-margin`), in the key mount’s frame of reference. It is therefore inaccurate as a measure of wall thickness on the x-y plane.

### Parameter `bevel`

A distance in mm.

This is applied at the very top of a wall, making up the difference between wall segments 0 and 1. It is applied again at the bottom, making up the difference between segments 3 and 4.

### Section `north`

As explained [elsewhere](intro.md), “north” refers to the side facing away from the user, barring yaw.

This section describes the shape of the wall on the north side of the keyboard. There are identical sections for the other cardinal directions.

#### Parameter `extent`

Two types of values are permitted here:

- The keyword `full`. This means a complete wall extending from the key mount all the way down to the ground via segments numbered 0 through 4 and a vertical drop thereafter.
- An integer corresponding to the last wall segment to be included. A zero means there will be no wall. No matter the number, there will be no vertical drop to the floor.

#### Parameter `parallel`

A distance in mm. The later wall segments extend this far away from the corners of their key mount, on its plane.

#### Parameter `perpendicular`

A distance in mm. The later wall segments extend this far away from the corners of their key mount, away from its plane.

### Section `east`

See `north`.

#### Parameter `extent`

#### Parameter `parallel`

#### Parameter `perpendicular`

### Section `south`

See `north`.

#### Parameter `extent`

#### Parameter `parallel`

#### Parameter `perpendicular`

### Section `west`

See `north`.

#### Parameter `extent`

#### Parameter `parallel`

#### Parameter `perpendicular`

⸻

This document was generated from the application CLI.

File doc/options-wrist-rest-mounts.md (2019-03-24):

# Options for connecting a wrist rest

Each heading in this document represents a recognized configuration key in YAML files for a DMOTE variant.

This specific document describes options for each “mount”, a pair of cuboid blocks used to anchor threaded fasteners for the `threaded` style of wrist rest, a parameter documented [here](options-main.md).

## Section `fasteners`

Threaded fasteners in the mount.

### Parameter `amount`

The number of vertically stacked screws in the mount. 1 by default.

### Parameter `diameter`

The ISO metric diameter of each fastener.

### Parameter `length`

The length in mm of each fastener.

### Section `height`

The vertical level of the fasteners.

#### Parameter `first`

The distance in mm from the bottom of the first fastener down to the ground level of the model.

#### Parameter `increment`

The vertical distance in mm from the center of each fastener to the center of the next.

## Parameter `anchoring`

One of:

- `case-side`: The `angle` parameter in this section determines the angle of the blocks and threaded fasteners in the mount. In effect, the plinth-side block is placed by `angle` and `distance`, while its own explicit `position` section of parameters is ignored.
- `mutual`: The `angle` and `distance` parameters are ignored. Each block is anchored to a separate and independent feature. The angle and distance between these two features determines the angle of the fasteners and the distance between the blocks.

## Parameter `angle`

The angle in radians of the mount, on the xy plane, counter-clockwise from the y axis. This parameter is only used with `case-side` anchoring.

## Section `blocks`

Blocks for anchoring threaded fasteners.

### Parameter `distance`

The distance in mm between the two posts in a mount. This parameter is only used with `case-side` anchoring.

### Parameter `width`

The width in mm of the face or front bezel on each block that will anchor a fastener.

### Section `case-side`

A block on the side of the keyboard case is mandatory.

#### Section `position`

Where to place the block.

##### Parameter `anchor`

An alias referring to a feature that anchors the block.

##### Parameter `corner`

A corner of the anchor. By default: `SSE` for south-by-southeast.

##### Parameter `offset`

A two-dimensional vector offset in mm from the anchor to the block.

#### Parameter `depth`

The thickness of the block in mm along the axis of the fastener(s).

#### Section `nuts`

Extra features for threaded nuts on the case side.

##### Section `bosses`

Nut bosses on the rear (interior) of the mount. You may want this if the distance between case and plinth is big enough for a nut. If that distance is too small, bosses can be counterproductive.

###### Parameter `include`

If `true`, include bosses.

### Section `plinth-side`

A block on the side of the wrist rest.

#### Section `position`

Where to place the block. This entire section is ignored in the `case-side` style of anchoring.

##### Parameter `anchor`

An alias referring to a feature that anchors the block. Whereas the case-side mount is typically anchored to a key, the plinth-side mount is typically anchored to a named point on the plinth.

##### Parameter `offset`

An offset in mm from the named feature to the block.

#### Parameter `depth`

The thickness of the mount in mm along the axis of the fastener(s). This is typically larger than the case-side depth to allow adjustment.

#### Parameter `pocket-height`

The height of the nut pocket inside the mounting plate, in mm.

With a large positive value, this will provide a chute for the nut(s) to go in from the top of the plinth, which allows you to hide the hole beneath the pad. With a large negative value, the pocket will instead open from the bottom, which is convenient if `depth` is small. With a small value or the default value of zero, it will be necessary to pause printing in order to insert the nut(s); this last option is therefore recommended for advanced users only.

### Parameter `aliases`

A map of short names to specific blocks, i.e. `case-side` or `plinth-side`. Such aliases are for use elsewhere in the configuration.

⸻

This document was generated from the application CLI.

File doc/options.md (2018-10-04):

# Configuration options

Each heading in this document represents a recognized configuration key in YAML files for a DMOTE variant.

This documentation was generated from the application CLI.

## Section `keycaps`

Keycaps are the plastic covers placed over the switches. Their shape will help determine the spacing between key mounts if the keyboard is curved. Negative space is also reserved for the caps.

### Parameter `preview`

If `true`, include models of the keycaps. This is intended for illustration in development. The models are not good enough for printing.

### Parameter `body-height`

The height in mm of each keycap, measured from top to bottom of the entire cap by itself.

An SA cap would be about 11.6 mm, DSA 7.3 mm.

### Parameter `resting-clearance`

The height in mm of the air gap between keycap and switch mount, in a resting state.

## Section `switches`

Electrical switches close a circuit when pressed. They cannot be printed. This section specifies how much space they need to be mounted.

### Parameter `style`

The switch type. One of:

 * `alps`: ALPS style switches, including Matias.
* `mx`: Cherry MX style switches.

### Parameter `travel`

The distance in mm that a keycap can travel vertically when mounted on a switch.

## Section `key-clusters`

This section describes where to put keys on the keyboard.

### Section `finger`

The main cluster of keys, for “fingers” in a sense excluding the thumb. Everything else is placed in relation to the finger cluster.

#### Parameter `style`

Cluster layout style. One of:

* `standard`: Both columns and rows have the same type of curvature applied in a logically consistent manner.
* `orthographic`: Rows are curved somewhat differently. This creates more space between columns and may prevent key mounts from fusing together if you have a broad matrix.

#### Parameter `matrix-columns`

A list of key columns. Columns are aligned with the user’s fingers. Each column will be known by its index in this list, starting at zero for the first item. Each item may contain:

* `rows-above-home`: An integer specifying the amount of keys on the far side of the home row in the column. If this parameter is omitted, the effective value will be zero.
* `rows-below-home`: An integer specifying the amount of keys on the near side of the home row in the column. If this parameter is omitted, the effective value will be zero.

For example, on a normal QWERTY keyboard, H is on the home row for purposes of touch typing, and you would probably want to use it as such here too, even though the matrix in this program has no necessary relationship with touch typing, nor with the matrix in your MCU firmware (TMK/QMK etc.). Your H key will then get the coordinates [0, 0] as the home-row key in the far left column on the right-hand side of the keyboard.

In that first column, to continue the QWERTY pattern, you will want `rows-above-home` set to 1, to make a Y key, or 2 to make a 6-and-^ key, or 3 to make a function key above the 6-and-^. Your Y key will have the coordinates [0, 1]. Your 6-and-^ key will have the coordinates [0, 2], etc.

Still in that first column, to finish the QWERTY pattern, you will want `rows-below-home` set to 2, where the two keys below H are N (coordinates [0, -1]) and Space (coordinates [0, -2]).

The next item in the list will be column 1, with J as [1, 0] and so on. On the left-hand side of a DMOTE, everything is mirrored so that [0, 0] will be G instead of H in QWERTY, [1, 0] will be F instead of J, and so on.

#### Parameter `aliases`

A map of short names to specific keys by coordinate pair. Such aliases are for use elsewhere in the configuration.

### Section `thumb`

A cluster of keys just for the thumb.

#### Section `position`

The thumb cluster is positioned in relation to the finger cluster.

##### Parameter `key-alias`

A finger key as named under `aliases` above.

##### Parameter `offset`

A 3-dimensional offset in mm from the indicated key.

#### Parameter `style`

As for the finger cluster.

#### Parameter `matrix-columns`

As for the finger cluster.

#### Parameter `aliases`

As for the finger cluster. Note, however, that aliases must be unique even between clusters.

### Section `aux0`

A cluster of keys not easily reachable by fingers or thumbs. This could be used for keys that shut down the computer, switch keyboard layout, modify backlighting, run large macros etc.

#### Section `position`

The aux0 cluster is positioned in relation to the finger cluster.

##### Parameter `key-alias`

As for the thumb cluster. Note this cannot be a thumb cluster alias.

##### Parameter `offset`

As for the thumb cluster.

#### Parameter `style`

As for the finger cluster.

#### Parameter `matrix-columns`

As for the finger cluster.

#### Parameter `aliases`

As for the finger cluster. Note, again, that aliases must be unique even between clusters.

## Section `by-key`

This section is special. It’s nested for all levels of specificity.

### Section `parameters`

This section, and everything in it, can be repeated at several levels: Here at the global level, for each key cluster, for each column, and at the row level. See below. Only the most specific option available for each key will be applied to that key.

#### Section `layout`

How to place keys.

##### Section `matrix`

Roughly how keys are spaced out to form a matrix.

###### Section `neutral`

The neutral point in a column or row is where any progressive curvature both starts and has no effect.

###### Parameter `column` at level 7

An integer column ID.

###### Parameter `row` at level 7

An integer row ID.

###### Section `separation`

Tweaks to control the systematic separation of keys. The parameters in this section will be multiplied by the difference between each affected key’s coordinates and the neutral column and row.

###### Parameter `column` at level 7

A distance in mm.

###### Parameter `row` at level 7

A distance in mm.

##### Section `pitch`

Tait-Bryan pitch, meaning the rotation of keys around the x axis.

###### Parameter `base`

An angle in radians. Set at a high level, this controls the general front-to-back incline of a key cluster.

###### Parameter `intrinsic`

An angle in radians. Intrinsic pitching occurs early in key placement. It is typically intended to produce a tactile break between two rows of keys, as in the typewriter-like terracing common on flat keyboards with OEM-profile or similarly angled caps.

The term “intrinsic” is used here because the key spins roughly around its own center. The term should not be confused with intrinsic rotations in the sense that each step is performed on a coordinate system resulting from previous operations.

###### Parameter `progressive`

An angle in radians. This progressive pitch factor bends columns lengthwise. If set to zero, columns are flat.

##### Section `roll`

Tait-Bryan roll, meaning the rotation of keys around the y axis.

###### Parameter `base`

An angle in radians. This is the “tenting” angle. Applied to the finger cluster, it controls the overall left-to-right tilt of each half of the keyboard.

###### Parameter `intrinsic`

An angle in radians, analogous to intrinsic pitching. Where more than one column of keys is devoted to a single finger at the edge of the keyboard, this can help make the edge column easier to reach, reducing the need to bend the finger (or thumb) sideways.

###### Parameter `progressive`

An angle in radians. This progressive roll factor bends rows lengthwise, which also gives the columns a lateral curvature.

##### Section `yaw`

Tait-Bryan yaw, meaning the rotation of keys around the z axis.

###### Parameter `base`

An angle in radians. Applied to the finger key cluster, this serves the purpose of allowing the user to keep their wrists straight even if the two halves of the keyboard are closer together than the user’s shoulders.

###### Parameter `intrinsic`

An angle in radians, analogous to intrinsic pitching.

##### Section `translation`

Translation in the geometric sense, displacing keys in relation to each other. Depending on when this translation takes places, it may have a a cascading effect on other aspects of key placement. All measurements are three-dimensional vectors in mm.

###### Parameter `early`

”Early” translation happens before other operations in key placement and therefore has the biggest knock-on effects.

###### Parameter `mid`

This happens after columns are styled but before base pitch and roll. As such it is a good place to adjust whole columns for relative finger length.

###### Parameter `late`

“Late” translation is the last step in key placement and therefore interacts very little with other steps. As a result, the z-coordinate, which is the last number in this vector, serves as a general vertical offset of the finger key cluster from the ground plane. If set at a high level, this controls the overall height of the keyboard, including the height of the case walls.

#### Section `channel`

Above each switch mount, there is a channel of negative space for the user’s finger and the keycap to move inside. This is only useful in those cases where nearby walls or webbing between mounts on the keyboard would otherwise obstruct movement.

##### Parameter `height`

The height in mm of the negative space, starting from the bottom edge of each keycap in its pressed (active) state.

##### Parameter `top-width`

The width in mm of the negative space at its top. Its width at the bottom is defined by keycap geometry.

##### Parameter `margin`

The width in mm of extra negative space around the edges of a keycap, on all sides.

#### Section `wall`

The walls of the keyboard case support the key mounts and protect the electronics. They are generated by an algorithm that walks around each key cluster.

This section determines the shape of the case wall, specifically the skirt around each key mount along the edges of the board. These skirts are made up of convex hulls wrapping sets of corner posts.

There is one corner post at each actual corner of every key mount. More posts are displaced from it, going down the sides. Their placement is affected by the way the key mounts are rotated etc.

##### Parameter `thickness`

A distance in mm.

This is actually the distance between some pairs of corner posts (cf. `key-mount-corner-margin`), in the key mount’s frame of reference. It is therefore inaccurate as a measure of wall thickness on the x-y plane.

##### Parameter `bevel`

A distance in mm.

This is applied at the very top of a wall, making up the difference between wall segments 0 and 1. It is applied again at the bottom, making up the difference between segments 3 and 4.

##### Section `north`

As explained [elsewhere](intro.md), “north” refers to the side facing away from the user, barring yaw.

This section describes the shape of the wall on the north side of the keyboard. There are identical sections for the other cardinal directions.

###### Parameter `extent`

Two types of values are permitted here:

* The keyword `full`. This means a complete wall extending from the key mount all the way down to the ground via segments numbered 0 through 4 and a vertical drop thereafter.
* An integer corresponding to the last wall segment to be included. A zero means there will be no wall. No matter the number, there will be no vertical drop to the floor.

###### Parameter `parallel`

A distance in mm. The later wall segments extend this far away from the corners of their key mount, on its plane.

###### Parameter `perpendicular`

A distance in mm. The later wall segments extend this far away from the corners of their key mount, away from its plane.

##### Section `east`

See `north`.

###### Parameter `extent`

###### Parameter `parallel`

###### Parameter `perpendicular`

##### Section `south`

See `north`.

###### Parameter `extent`

###### Parameter `parallel`

###### Parameter `perpendicular`

##### Section `west`

See `north`.

###### Parameter `extent`

###### Parameter `parallel`

###### Parameter `perpendicular`

### Section `clusters` ← overrides go in here

This is an anchor point for overrides of the `parameters` section described above. Overrides start at the key cluster level. This section therefore permits keys that identify specific key clusters.

For each such key, two subsections are permitted: A new, more specific `parameters` section and a `columns` section. Columns are indexed by their ordinal integers or the words “first” or “last”, which take priority.

A column can have its own `parameters` and its own `rows`, which are indexed in relation to the home row or again with “first” or “last”. Finally, each row can have its own `parameters`, which are specific to the full combination of cluster, column and row.

WARNING: Due to a peculiarity of the YAML parser, take care to quote your numeric column and row indices as strings.

In the following example, the parameter `P`, which is not really supported, will have the value “true” for all keys except the one closest to the user (“first” row) in the second column from the left on the right-hand side of the keyboard (column 1; this is the second from the right on the left-hand side of the keyboard; note quotation marks).

```by-key:
  parameters:
    P: true
  clusters:
    finger:
      columns:
        "1":
          rows:
            first:
              parameters:
                P: false
```

## Section `case`

Much of the keyboard case is generated from the `wall` parameters above. This section deals with lesser features of the case.

### Parameter `key-mount-thickness`

The thickness in mm of each switch key mounting plate.

### Parameter `key-mount-corner-margin`

The thickness in mm of an imaginary “post” at each corner of each key mount. Copies of such posts project from the key mounts to form the main walls of the case.

`key-mount-thickness` is similarly the height of each post.

### Parameter `web-thickness`

The thickness in mm of the webbing between switch key mounting plates and of the rear housing’s walls and roof.

### Section `rear-housing`

The furthest row of the key cluster can be extended into a rear housing for the MCU and various other features.

#### Parameter `include`

If `true`, add a rear housing. Please arrange case walls so as not to interfere, by removing them along the far side of the last row of key mounts in the finger cluster.

#### Parameter `west-foot`

If `true`, add a foot plate at ground level by the far inward corner of the rear housing. The height of the plate is controlled by the `foot-plates` section below.

#### Parameter `distance`

The horizontal distance in mm between the furthest key in the row and the roof of the rear housing.

#### Parameter `height`

The height in mm of the roof, over the floor.

#### Section `offsets`

Modifiers for the size of the roof. All are in mm.

##### Parameter `north`

The extent of the roof on the y axis; its horizontal depth.

##### Parameter `west`

The extent on the x axis past the first key in the row.

##### Parameter `east`

The extent on the x axis past the last key in the row.

#### Section `fasteners`

Threaded bolts can run through the roof of the rear housing, making it a hardpoint for attachments like a stabilizer to connect the two halves of the keyboard.

##### Parameter `diameter`

The ISO metric diameter of each fastener.

##### Parameter `bosses`

If `true`, add nut bosses to the ceiling of the rear housing for each fastener. Space permitting, these bosses will have some play on the north-south axis, to permit adjustment of the angle of the keyboard halves under a stabilizer.

##### Section `west`

A fastener on the inward-facing end of the rear housing.

###### Parameter `include`

If `true`, include this fastener.

###### Parameter `offset`

A one-dimensional offset in mm from the inward edge of the rear housing to the fastener. You probably want a negative number if any.

##### Section `east`

A fastener on the outward-facing end of the rear housing. All parameters are analogous to those for `west`.

###### Parameter `include`

###### Parameter `offset`

### Section `back-plate`

Given that independent movement of each half of the keyboard is not useful, each half can include a mounting plate for a stabilizing ‘beam’. That is a straight piece of wood, aluminium, rigid plastic etc. to connect the two halves mechanically and possibly carry the wire that connects them electrically.

This option is similar to rear housing, but the back plate block provides no interior space for an MCU etc. It is solid, with holes for threaded fasteners including the option of nut bosses.

#### Parameter `include`

If `true`, include a back plate block.

#### Parameter `beam-height`

The nominal vertical extent of the back plate in mm. Because the plate is bottom-hulled to the floor, the effect of this setting is on the area of the plate above its holes.

#### Section `fasteners`

Two threaded bolts run through the back plate.

##### Parameter `diameter`

The ISO metric diameter of each fastener.

##### Parameter `distance`

The horizontal distance between the fasteners.

##### Parameter `bosses`

If `true`, cut nut bosses into the inside wall of the block.

#### Section `position`

The block is positioned in relation to a key mount.

##### Parameter `key-alias`

A named key where the block will attach. The vertical component of its position will be ignored.

##### Parameter `offset`

An offset in mm from the middle of the north wall of the selected key, at ground level, to the middle of the base of the back plate block.

### Section `leds`

Support for light-emitting diodes in the case walls.

#### Parameter `include`

If `true`, cut slots for LEDs out of the case wall, facing the space between the two halves.

#### Parameter `amount`

The number of LEDs.

#### Parameter `housing-size`

The length of the side on a square profile used to create negative space for the housings on a LED strip. This assumes the housings are squarish, as on a WS2818.

The negative space is not supposed to penetrate the wall, just make it easier to hold the LED strip in place with tape, and direct its light. With that in mind, feel free to exaggerate by 10%.

#### Parameter `emitter-diameter`

The diameter of a round hole for the light of an LED.

#### Parameter `interval`

The distance between LEDs on the strip. You may want to apply a setting slightly shorter than the real distance, since the algorithm carving the holes does not account for wall curvature.

### Parameter `tweaks`

Additional shapes. This is usually needed to bridge gaps between the walls of the finger and key clusters.

The expected value here is an arbitrarily nested structure starting with a list. Each item in the list can follow one of the following patterns:

* A leaf node. This is a 3- or 4-tuple list with contents specified below.
* A map, representing an instruction to combine nested items in a specific way.
* A list of any combination of the other two types. This type exists at the top level and as the immediate child of each map node.

Each leaf node identifies a particular set of key mount corner posts. These are identical to the posts used to build the walls (see above), but this section gives you greater freedom in how to combine them. A leaf node must contain:

* A key alias defined under `key-clusters`.
* A key corner ID, such as `NNE` for north by north-east.
* A wall segment ID, which is an integer from 0 to 4.

Together, these identify a starting segment. Optionally, a leaf node may contain a second segment ID trailing the first. In that case, the leaf will represent the convex hull of the first and second indicated segments, plus all in between.

By default, a map node will create a convex hull around its child nodes. However, this behaviour can be modified. The following keys are recognized:

* `to-ground`: If `true`, child nodes will be extended vertically down to the ground plane, as with a `full` wall.
* `chunk-size`: Any integer greater than 1. If this is set, child nodes will not share a single convex hull. Instead, there will be a sequence of smaller hulls, each encompassing this many items.
* `highlight`: If `true`, render the node in OpenSCAD’s highlighting style. This is convenient while you work.
* `hull-around`: The list of child nodes. Required.

In the following example, `A` and `B` are aliases that would be defined elsewhere. The example is interpreted to mean that a plate should be created stretching from the south-by-southeast corner of `A` to the north-by-northeast corner of `B`. Due to `chunk-size` 2, that first plate will be joined, not hulled, with a second plate from `B` back to a different corner of `A`, with a longer stretch of wall segments down the corner of `A`.

```case:
  tweaks:
    - chunk-size: 2
      hull-around:
      - [A, SSE, 0]
      - [B, NNE, 0]
      - [A, SSW, 0, 4]
```

### Section `foot-plates`

Optional flat surfaces at ground level for adding silicone rubber feet or cork strips etc. to the bottom of the keyboard to increase friction and/or improve feel, sound and ground clearance.

#### Parameter `include`

If `true`, include foot plates.

#### Parameter `height`

The height in mm of each mounting plate.

#### Parameter `polygons`

A list describing the horizontal shape, size and position of each mounting plate as a polygon.

## Section `mcu`

This is short for ”micro-controller unit”. Each half has one.

### Parameter `preview`

If `true`, render a visualization of the MCU for use in development.

### Parameter `type`

A symbolic name for a commercial product. Currently, only `promicro` is supported, referring to any MCU with the dimensions of a SparkFun Pro Micro.

### Parameter `margin`

A general measurement in mm of extra space around each part of the MCU, including PCB and USB connector. This is applied to DMOTE components meant to hold the MCU in place, accounting for printing inaccuracy as well as inaccuracies in manufacturing the MCU.

### Section `position`

Where to place the MCU.

#### Parameter `prefer-rear-housing`

If `true` and `rear-housing` is included, place the MCU in relation to the rear housing. Otherwise, place the MCU in relation to a key mount identified by `key-alias`.

#### Parameter `key-alias`

The name of a key at which to place the MCU if `prefer-rear-housing` is `false` or rear housing is not included.

#### Parameter `corner`

A code for a corner of the rear housing or of `key-alias`. This determines both the location and facing of the MCU.

#### Parameter `offset`

A 3D offset in mm, measuring from the `corner`.

#### Parameter `rotation`

A vector of 3 angles in radians. This parameter governs the rotation of the MCU around its anchor point in the front. You would not normally need this for the MCU.

### Section `support`

The support structure that holds the MCU PCBA in place.

#### Parameter `style`

The style of the support. Available styles are:

* `lock`: A separate physical object that is bolted in place over the MCU. This style is appropriate only with a rear housing, and then only when the PCB aligns with a long wall of that housing. It has the advantage that it can hug the connector on the PCB tightly, thus preventing a fragile surface-mounted connector from breaking off.
* `stop`: A gripper that holds the MCU in place at its rear end. This gripper, in turn, is held up by key mount webbing and is thus integral to the keyboard, not printed separately like the lock. This style does not require rear housing.

#### Parameter `preview`

If `true`, render a visualization of the support in place. This applies only to those parts of the support that are not part of the case model.

#### Parameter `height-factor`

A multiplier for the width of the PCB, producing the height of the support actually touching the PCB.

#### Parameter `lateral-spacing`

A lateral 1D offset in mm. With rear housing, this creates space between the rear housing itself and the back of the PCB’s through-holes, so it should be roughly matched to the length of wire overshoot. Without rear housing, it isn’t so useful but it does work analogously.

#### Section `lock`

Parameters relevant only with a `lock`-style support.

##### Section `fastener`

Threaded fasteners—a nut and a bolt—connect the lock to the case.

###### Parameter `style`

A supported bolt cap style.

###### Parameter `diameter`

The ISO metric diameter of the fastener.

##### Section `socket`

A housing around the USB connector on the MCU.

###### Parameter `thickness`

The wall thickness of the socket.

##### Section `bolt`

The part of a `lock`-style support that does not print as part of the keyboard case. This bolt, named by analogy with a lock, is not to be confused with the threaded fasteners holding it in place.

###### Parameter `clearance`

The distance of the bolt from the populated side of the PCB. This distance should be slightly greater than the height of the tallest component on the PCB.

###### Parameter `overshoot`

The distance across which the bolt will touch the PCB at the mount end. Take care that this distance is free of components on the PCB.

###### Parameter `mount-length`

The length of the base that contains the threaded fasteners used to secure the bolt over the MCU. This is in addition to `overshoot` and goes in the opposite direction, away from the PCB.

###### Parameter `mount-thickness`

The thickness of the mount. You will need a threaded fastener slightly longer than this.

#### Section `stop`

Parameters relevant only with a `stop`-style support.

##### Parameter `key-alias`

The name of a key where a stop will start to attach itself.

##### Parameter `direction`

A direction in the matrix from the named key. The stop will attach to a hull of four neighbouring key mount corners in this direction.

##### Section `gripper`

The shape of the part that grips the PCB.

###### Parameter `notch-depth`

The horizontal depth of the notch in the gripper that holds the PCB. The larger this number, the more flexible the case has to be to allow assembly.

Note that while this is similar in effect to `lock`-style `overshoot`, it is a separate parameter because of the flexion limit.

###### Parameter `total-depth`

The horizontal depth of the gripper as a whole in line with the PCB.

###### Parameter `grip-width`

The width of a protrusion on each side of the notch.

## Section `connection`

Because the DMOTE is split, there must be a signalling connection between its two halves. This section adds a socket for that purpose. For example, this might be a type 616E female for a 4P4C “RJ9” plug.

### Parameter `socket-size`

The size of a hole in the case, for the female to fit into.

### Section `position`

Where to place the socket. Equivalent to `connection` → `mcu`.

#### Parameter `prefer-rear-housing`

#### Parameter `key-alias`

#### Parameter `corner`

#### Parameter `raise`

If `true`, and the socket is being placed in relation to the rear housing, put it directly under the ceiling, instead of directly over the floor.

#### Parameter `offset`

#### Parameter `rotation`

## Section `wrist-rest`

An optional extension to support the user’s wrist.

### Parameter `include`

If `true`, include a wrist rest with the keyboard.

### Parameter `style`

The style of the wrist rest. Available styles are:

* `threaded`: threaded fasteners connect the case and wrist rest. This works with a great variety of keyboard shapes and will allow adjusting the position of the wrist rest for different hands.
* `solid`: a printed plastic bridge along the ground as part of the model. This has more limitations, both in manufacture and in use. It includes a hook on the near outward side of the case, which will only be useful if the case wall at that point is short and finger column 2 is positioned and walled in such a way that the solid bridge can be wedged between the hook and the column.

### Parameter `preview`

Preview mode. If `true`, this puts a model of the wrist rest in the same OpenSCAD file as the case. That model is simplified, intended for gauging distance, not for printing.

### Section `position`

The wrist rest is positioned in relation to a key mount.

#### Parameter `key-alias`

A named key where the wrist rest will attach. The vertical component of its position will be ignored.

#### Parameter `offset`

An offset in mm from the selected key to one corner of the base of the wrist rest. Specifically, it is the corner close to the keyboard case, on the right-hand side of the right-hand half.

### Section `shape`

The wrist rest needs to fit the user’s hand.

#### Parameter `plinth-base-size`

The size of the plinth up to but not including the narrowing upper lip and rubber parts.

#### Parameter `chamfer`

A distance in mm. The plinth is shrunk and then regrown by this much to chamfer its corners.

#### Parameter `lip-height`

The height of a narrowing, printed lip between the base of the plinth and the rubber part.

#### Section `pad`

The top of the wrist rest should be printed or cast in a soft material, such as silicone rubber.

##### Parameter `surface-heightmap`

A filepath. The path, and file, will be interpreted by OpenScad, using its [`surface()` function](https://en.wikibooks.org/wiki/OpenSCAD_User_Manual/Other_Language_Features#Surface).

The file should contain a heightmap to describe the surface of the rubber pad.

##### Section `height`

The piece of rubber extends a certain distance up into the air and down into the plinth. All measurements in mm.

###### Parameter `surface-range`

The vertical range of the heightmap. Whatever values are in the heightmap will be normalized to this scale.

###### Parameter `lip-to-surface`

The part of the rubber pad between the top of the lip and the point where the heightmap comes into effect. This is useful if your heightmap itself has very low values at the edges, such that moulding and casting it without a base would be difficult.

###### Parameter `below-lip`

The depth of the rubber wrist support, measured from the top of the lip, going down into the plinth. This part of the pad just keeps it in place.

### Section `fasteners`

This is only relevant with the `threaded` style of wrist rest.

#### Parameter `amount`

The number of fasteners connecting each case to its wrist rest.

#### Parameter `diameter`

The ISO metric diameter of each fastener.

#### Parameter `length`

The length in mm of each fastener.

#### Section `height`

The vertical level of the fasteners.

##### Parameter `first`

The distance in mm from the bottom of the first fastener down to the ground level of the model.

##### Parameter `increment`

The vertical distance in mm from the center of each fastener to the center of the next.

#### Section `mounts`

The mounts, or anchor points, for each fastener on each side.

##### Parameter `width`

The width in mm of the face or front bezel on each connecting block that will anchor a fastener.

##### Section `case-side`

The side of the keyboard case.

###### Parameter `key-alias`

A named key. A mount point on the case side will be placed near this key.

###### Parameter `offset`

An two-dimensional vector offset in mm from the key to the mount.

###### Parameter `depth`

The thickness of the mount in mm along the axis of the fastener(s).

###### Section `nuts`

Extra features for threaded nuts on the case side.

###### Section `bosses` at level 7

Nut bosses on the rear (interior) of the mount. You may want this if the distance between case and plinth is big enough for a nut. If that distance is too small, bosses can be counterproductive.

###### Parameter `include` at level 8

If `true`, include bosses.

##### Section `plinth-side`

The side of the wrist rest.

###### Parameter `offset`

The offset in mm from the corner of the plinth to the fastener mount point attached to the plinth.

###### Parameter `depth`

The thickness of the mount in mm along the axis of the fastener(s). This is typically larger than the case-side depth to allow adjustment.

###### Parameter `pocket-scale`

A scale coefficient for the nut model used to carve out the pocket. This defaults to 1. You would need to set it higher if your printing material, in combination with your nozzle diameter, shrinks or expands in such a way that the deep pocket would otherwise be too tight.

###### Parameter `pocket-height`

The height of the nut pocket inside the mounting plate, in mm.

With a large positive value, this will provide a chute for the nut(s) to go in from the top of the plinth, which allows you to hide the hole beneath the pad. With a large negative value, the pocket will instead open from the bottom, which is convenient if `depth` is small. With a small value or the default value of zero, it will be necessary to pause printing in order to insert the nut(s); this last option is therefore recommended for advanced users only.

### Section `solid-bridge`

This is only relevant with the `solid` style of wrist rest.

#### Parameter `width`

The width in mm of the land bridge between the case and the plinth.

On the right-hand side of the keyboard, the bridge starts from the wrist rest `key-alias` and extends this many mm to the left.

The value of this parameter, and the shape of the keyboard case, should be arranged in a such a way that the land bridge is wedged in place by a vertical wall on that left side.

#### Parameter `height`

The height in mm of the land bridge between the case and the plinth.

## Section `mask`

A box limits the entire shape, cutting off any projecting byproducts of the algorithms. By resizing and moving this box, you can select a subsection for printing. You might want this while you are printing prototypes for a new style of switch, MCU support etc.

### Parameter `size`

The size of the mask in mm. By default, `[1000, 1000, 1000]`.

### Parameter `center`

The position of the center point of the mask. By default, `[0, 0, 500]`, which is supposed to mask out everything below ground level.

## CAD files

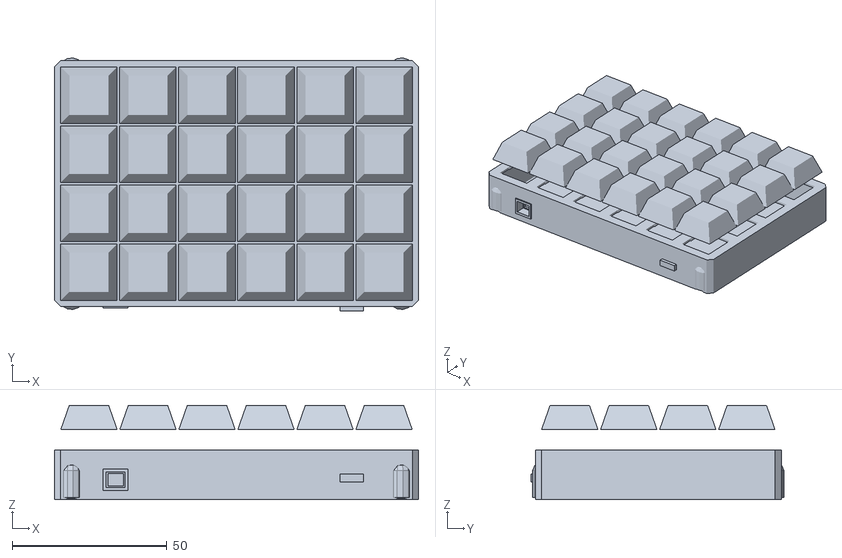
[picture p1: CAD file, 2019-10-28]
config/lets_split/left_demo.stl
117.5 x 81.7 x 30.5

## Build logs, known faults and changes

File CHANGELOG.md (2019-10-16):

# Change log
This log follows the conventions of
[keepachangelog.com](http://keepachangelog.com/). It picks up from DMOTE
version 0.2.0, thus covering only a fraction of the project’s history.

## [Unreleased]
Nothing yet.

## [Version 0.5.1] - 2019-10-16
### Fixed
- Added a parser for one more of `dmote-keycap`’s parameters (`supported`),
  thus allowing supports to be turned off for keycap models rendered through
  this application.

## [Version 0.5.0] - 2019-07-21
### Changed
- Secondary aliases (`secondaries`) are now a map and case `tweaks` are
  likewise nested underneath a layer of names. Both of these structural
  changes add power to the configuration layer, reducing the need for
  duplication of data.
- Fixes that make the height of the case easier to manage constitute changes
  to previous behaviour:
    - Key mounting plates, which were previously located immediately on top of
      the nominal position of each key, are now below the nominal. In other
      words, key mounting plates have dropped down by the thickness of the
      mounting plates. This means that, on a completely flat keyboard, the
      configured height of each key mount is now the height of the case.
        - When you change key mount thickness, the difference is now internal
          to the keyboard and will no longer affect the relative positions of
          the switches.
        - To match this change, mount thickness is no longer a factor in
          computing curvature. This in turn affects the nominal positions of
          keys. It effectively recalibrates the scale of matrix separation,
          correcting it so that the default value of value of zero is more
          likely to create a good design.
    - Webbing and case walls etc. are (still) governed by key mounts, so they
      have also dropped down.
    - Similarly, the configured height of the rear housing is now its actual
      height, not the centre height of the cuboids that make up its corners.
- Moved bundled YAML.
    - The entire `resources/opt` folder is now at `config`.
    - Most of `resources/opt/default.yaml` has been renamed (to
      `config/dmote/base.yaml`) and is now less privileged.
    - A simple `make` has the same effect as before but passes more
      arguments to achieve it. Without arguments, the Clojure
      application now describes an unusable single-button keyboard.
- Changes to the bundled 62-key DMOTE configuration:
    - Switched from M3 to M4 screws for attaching the bottom plate and for
      locking the MCU PCB in place. This makes for quicker previews and easier
      printing.
    - Switched from flat to conical points for bottom-plate fasteners, just
      so the holes are easier to slice without getting interior supports.
    - Minor tweaks, like renaming the `maquette-dsa` style to `default`
      and removing a secondary anchor obviated by new controls for rear-housing
      post thickness.
- Replaced the nut boss in an MCU lock bolt with printed threading of the hole.

### Added
- Key mounting plates responsive to key `unit-size` for ease with oblong keys.
- A bundled 12-key macropad configuration, mainly as an object lesson.
- A `split` parameter at the highest level. This is false by default and absent
  in `config/base.yaml`, to enable macropads and relatively regular keyboards.
  It’s true in `config/dmote/base.yaml`.
    - An `include` parameter for the connection metasocket. This is false by
      default and true in `config/dmote/base.yaml`. Its effect is contingent
      upon the `split` parameter.
- An `include` parameter for MCU PCBA support. This is false by
  default and absent in `config/base.yaml`, mainly to enable tutorials where
  the MCU support does not pose a distraction, and partly to allow custom
  alternatives to the supported styles.
- More finely grained control for dimensions previously governed by general
  case webbing thickness.
    - New parameters for rear-housing wall and roof thickness.
    - A new parameter for connection socket wall thickness.
- A new implementation of the `solid` style of wrist rest attachment,
  with a bundled example configuration powered by the new structure of
  `secondaries` and case `tweaks`. In the example, the case and wrist rest
  are one piece of plastic. In a previous implementation, removed in version
  0.3.0, the two were separate pieces that snapped together, which put more
  requirements on the shape of the case and was not useful enough.
- A new DFM parameter, `fastener-plate-offset`, for tighter holes through
  bottom plates.
- A new bundled configuration fragment, `config/dmote/mx.yaml`, imposing
  MX-style switches on the DMOTE.
- More features added to `config/dactyl_manuform/base.yaml`,
  reconstructing part of the classic upstream shape as a configuration.
- A primitive means of combining YAML files by passing them as targets to Make.
  This does not work as intended and may be removed in future.

### Fixed
- Renamed a file (from `aux` to `auxf`) to work around file system
  restrictions inherited from MS DOS into current versions of Windows.
- Corrected placement of wrist-rest fastener anchors for the thickness of the
  bottom plate.
- Fixed a bad function call for `stop`-style MCU support.
- Slightly more accurate models of switches.

### Developer
- In the interest of versatility, the Clojure code no longer refers to any YAML
  files. Instead, the default configuration values that are built into the code
  itself are slightly richer, to prevent crashing without YAML files.
- Restructured the makefile, renaming some of the phony targets (e.g.
  `visualization` to `vis`) and removing others for the present. `make all` no
  longer exercises as much of the code.

## [Version 0.4.0] - 2019-06-06
### Changed
- Moved and replaced some parameters:
    - Both the `keycaps` and `switches` sections have been replaced. There is
      now a `keys` section that defines one or more `styles`, as well as a
      `key-style` parameter in the nesting `by-key` section of parameters.
    - The `to-ground` key for case tweaks has been renamed to `at-ground` for
      clarity with respect to a new `above-ground` key.
    - The general `error` parameter for DFM has been renamed `error-general`.
- Changed default.yaml from a 60-key layout with a user-facing 1-key `aux0`
  cluster to a 62-key layout (31 on each half) with a 2-key `aux0` cluster at
  the opposite corner and facing away from the user.

### Added
- Support for multiple, named styles of keys.
    - This includes some with enough detail on the keycaps to permit printing.
      These printable models are now among the outputs of the application.
- Improved case `tweaks`.
    - Tweaks are no longer restricted to key aliases.
        - Any named feature can be used in a leaf node.
        - It is no longer necessary to specify a corner or segment for a tweak.
    - Tweaks can now target bottom plates without impacting case walls.
      There is a new configuration key for this (`above-ground`, which must be
      turned off to see the new behaviour).
    - Added a `secondaries` parameter for named features that are just points
      in space, placed in relation to other named features. Used in `tweaks`,
      these secondaries give greater freedom in shaping the case.
- Added a `resolution` section to the parameters.
    - By default, already-existing resolution parameters (both of them are for
      wrist-rest pads) will be disabled by a default-negative new `include`
      parameter in the new section.
    - The new section also provides a means of rendering curved surfaces
      elsewhere in more detail.
- Added a `thickness` parameter specific to the threaded anchors for
  bottom-plate screws.

### Fixed
- Improved the fit of a bottom plate for the case, at the cost of
  greater rendering complexity.
- Reduced risk and impact of collision between nut bosses built into the
  rear housing and the interior negative of the socket for connecting the
  two halves, by reducing the thickness of one part of the negative.

### Developer
- Took advantage of new developments in general-purpose libraries:
    - Outsourced file authoring to `scad-app` for improved CPU thread scaling,
      rendering feedback and face-size constraints.
    - `scad-tarmi` lofting replaced `pairwise-hulls` and `triangle-hulls`.
    - `scad-tarmi` flex functions obviated several separate functions for
      object placement and reasoning about that placement.
    - `scad-tarmi` coordinate specs replaced locals.
    - Featureful `dmote-keycap` models replaced internal maquettes.
- Made the rosters of models and module definitions reactive to the
  configuration.
    - Converted keycaps and switches to OpenSCAD modules.
- Changed the merge order in the `reckon-from-anchor` function to make
  secondaries useful in tweaks.

## [Version 0.3.0] - 2019-02-18
### Changed
- Moved and replaced some options:
    - Dimensions of `keycaps` have moved into nestable `parameters` under
      `by-key`.
    - `key-alias` settings have been merged into `anchor`. `anchor` can now
      refer to a variety of features either by alias or by a built-in and
      reserved name like `rear-housing` or `origin`. In some cases, it is now
      possible to anchor features more freely as a result.
    - Moved `case` → `rear-housing` → `offsets` into
      `case` → `rear-housing` → `position`.
    - Moved `case` → `rear-housing` → `distance` into
      `case` → `rear-housing` → `position` → `offsets` as `south`.
    - Renamed the `key-corner` input of `case` → `foot-plates` → `polygons`
      to `corner`.
    - Removed the option `case` → `rear-housing` → `west-foot` in favour of
      more general `foot-plates` functionality.
    - Removed `wrist-rest` → `shape` → `plinth-base-size` in favour of settings
      (in a new `spline` section) that do not restrict you to a cuboid.
    - Removed `wrist-rest` → `shape` → `chamfer`. You can achieve the old
      chamfered, boxy look by setting spline resolution to 1 and manually
      positioning the corners of the wrist rest for it.
    - Moved `wrist-rest` → `shape` → `lip-height` to
      `wrist-rest` → `shape` → `lip` → `height`.
    - Moved `wrist-rest` → `shape` → `pad` → `surface-heightmap`
      to `wrist-rest` → `shape` → `pad` → `surface` → `heightmap` → `filepath`.
    - Substantial changes to `wrist-rest` → `fasteners`, which has been castled
      to `wrist-rest` → `mounts` and is now a list.
- Removed the implementation of the `solid` style of wrist rest attachment.
  This was reimplemented in version 0.5.0.
- Removed the option `wrist-rest` → `fasteners` → `mounts` → `plinth-side` →
  `pocket-scale`, obviated by a new generic `dfm` feature.
- Renamed the ‘finger’ key cluster to ‘main‘.
- As a side effect of outsourcing the design of threaded fasteners to
  `scad-tarmi`, the `flat` style of bolt head has been renamed to
  the more specific `countersunk`.
- Removed `create-models.sh`, adding equivalent functionality to the Clojure
  application itself (new flags: `--render`, `--renderer`).
- Added intermediate `scad` and `stl` folders under `things`.
- Split generated documentation (`options.md`) into four separate documents
  (`options-*.md`).

### Added
- This log.
- Support for generating a bottom plate that closes the case.
    - This includes support for a separate plate for the wrist rest, and a
      combined plate that joins the two models.
- Improvements to wrist rests.
    - Arbitrary polygonal outlines and vertically rounded edges, without a
      height map.
    - Tilting.
    - Support for placing wrist rests in relation to their point
      of attachment to the case using a new `anchoring` parameter.
    - Support for multiple mount points.
    - Support for naming the individual blocks that anchor a wrist rest.
    - Support for placing wrist rests in relation to a specific corner of a key.
      In the previous version, the attachment would be to the middle of the key.
    - Parametrization of mould wall thickness.
    - Parametrization of sprues.
- Support for naming your key clusters much more freely, and/or adding
  additional clusters. Even the new ‘main’ cluster is optional.
    - Support for a `cluster` parameter to `case` → `rear-housing` →
      `position`. The rear housing would previously be attached to the finger
      cluster.
    - Support for a `cluster` parameter to `case` → `leds` → `position`.
      LEDs would previously be attached to the finger cluster.
    - Support for anchoring any cluster to any other, within logical limits.
- Parametrization of keycap sizes, adding support for sizes other than 1u in
  both horizontal dimensions, as well as diversity in keycap height and
  clearance.
- Support for a filename whitelist in the CLI.
- Support for placing `foot-plates` in relation to objects other than keys.
- Support for generic compensation for slicer and printer inaccuracies in the
  xy plane through a new option, `dfm` → `error`.

### Fixed
- Improved support for Windows by using `clojure.java.io/file` instead of
  string literals with Unix-style file-path separators.
- Strengthened parameter validation for nested sections.

### Developer
- Significant restructuring of the code base for separation of concerns.
    - Switched to docstring-first function definitions.
    - Shifted more heavily toward explicit namespacing and took the opportunity
      to shorten some function names in the matrix module and elsewhere.
- Added a dependency on `scad-tarmi` for shorter OpenSCAD code and more
  capable models of threaded fasteners.
- Rearranged derived parameter structure somewhat to support arbitrary key
  clusters and the use of aliases for more types of objects (other than keys).
- Removed the `new-scad` function without replacement.
- Removed a dependency on `unicode-math`. The requisite version of the library
  had not been deployed to Clojars and its use was cosmetic.

[Unreleased]: https://github.com/veikman/dactyl-keyboard/compare/dmote-v0.5.1...HEAD
[Version 0.5.1]: https://github.com/veikman/dactyl-keyboard/compare/dmote-v0.5.0...dmote-v0.5.1
[Version 0.5.0]: https://github.com/veikman/dactyl-keyboard/compare/dmote-v0.4.0...dmote-v0.5.0
[Version 0.4.0]: https://github.com/veikman/dactyl-keyboard/compare/dmote-v0.3.0...dmote-v0.4.0
[Version 0.3.0]: https://github.com/veikman/dactyl-keyboard/compare/dmote-v0.2.0...dmote-v0.3.0

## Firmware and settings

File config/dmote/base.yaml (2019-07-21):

# Configuration fragment for the base of a 62-key DMOTE.

split: true
keys:
  styles:
    minimal-short:  # A printable minimal key with a thin top.
      style: minimal
      top-size: [9, 9, 1.6]
      skirt-thickness: 2.4
    minimal-tall:  # Similar but with a thicker plate above the stem.
      style: minimal
      top-size: [9, 9, 3]
      skirt-thickness: 2.4
key-clusters:
  main:
    position:
      anchor: origin
      offset: [0, 0, 19.5]
    matrix-columns:
    - rows-above-home: 1
      rows-below-home: 1
    - rows-above-home: 1
      rows-below-home: 2
    - rows-above-home: 1
      rows-below-home: 3
    - rows-above-home: 1
      rows-below-home: 2
    - rows-below-home: 2
    - rows-below-home: 2
    aliases:
      m00: [0, first]
      m01: [1, first]
      m02: [2, first]
      m03: [3, first]
      back0: [0, last]
      back1: [1, last]
      m10: [3, last]
      m11: [3, 0]
      m12: [4, last]
      m13: [last, last]
      near-right: [last, first]
  thumb0:
    position:
      anchor: m01
      offset: [-8, -16, 29]
    matrix-columns:
    - rows-above-home: 1
      rows-below-home: 1
    - rows-above-home: 1
    aliases:
      tc: [first, 0]
      t1: [first, last]
      t2: [last, last]
      t3: [last, first]
      t4: [first, first]
  thumb1:
    position:
      anchor: t4
      offset: [-12, 5, -17.5]
    matrix-columns:
    - rows-above-home: 1
    aliases:
      t0: [first, last]
      t5: [first, first]
  aux0:
    position:
      anchor: m12
      offset: [1.5, 17, 6]
    matrix-columns:
    - rows-above-home: 0
    - rows-above-home: 0
    aliases:
      a0: [0, 0]
      a1: [1, 0]
by-key:
  clusters:
    main:
      parameters:
        layout:
          matrix:
            neutral:
              column: 2
            separation:
              row: 0
              column: 0
          pitch:
            base: 0.5
            progressive: 0.3
            intrinsic: -0.1
          roll:
            base: 0.2
            progressive: 0.06
          yaw:
            base: 0.03
      columns:
        "0":
          parameters:
            key-style: minimal-tall
            layout:
              pitch:
                base: 0.34
                progressive: 0.6
                intrinsic: 0
              roll:
                intrinsic: 0.3
              yaw:
                base: -0.04
              translation:
                mid: [0.5, -10, 4]
            wall:
              north:
                extent: 0
              south:
                extent: 0
          rows:
            "0":
              parameters:
                key-style: minimal-short
                layout:
                  translation:
                    early: [0, 0, -1]
        "1":
          parameters:
            layout:
              pitch:
                base: 0.6
                progressive: 0.4
              translation:
                mid: [0, -1, 0]
            wall:
              north:
                extent: 0
              south:
                extent: 0
              west:
                extent: 0
          rows:
            first:
              parameters:
                layout:
                  pitch:
                    intrinsic: -0.3
                  yaw:
                    intrinsic: -0.03
                  translation:
                    early: [-1, -5.2, 8]
                channel:
                  top-width: 15
            "-1":
              parameters:
                layout:
                  pitch:
                    intrinsic: -0.2
                  translation:
                    early: [0, -0.6, 2]
            "0":
              parameters:
                key-style: minimal-short
                layout:
                  translation:
                    early: [1, 0, 0]
            "1":
              parameters:
                key-style: minimal-tall
                layout:
                  translation:
                    early: [1, -1, 0]
        "2":
          parameters:
            layout:
              pitch:
                progressive: 0.4
              translation:
                mid: [0, 3, -3]
            wall:
              north:
                extent: 0
              east:
                extent: 1
              south:
                extent: 1
              west:
                extent: 0
          rows:
            "-3":
              parameters:
                layout:
                  pitch:
                    intrinsic: -0.7
                  translation:
                    early: [0, -14, 7]
                wall:
                  east:
                    extent: 4
            "-2":
              parameters:
                layout:
                  pitch:
                    intrinsic: -0.3
                  translation:
                    early: [0, -3, 2.5]
            last:
              parameters:
                key-style: minimal-tall
                layout:
                  translation:
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

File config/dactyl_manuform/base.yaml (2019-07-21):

# A configuration fragment for Tom Short’s Dactyl-ManuForm, ca. v0.4.

# The long-term goal with this file is to have it produce Short’s design
# through the DMOTE application for upstream compatibility.

# As of DMOTE v0.5.0, that is not yet possible, because:
# - No internal shelf for the MCU.
# - No USB A.
# - No wire hooks.
# - Bottom plating does not project from screw anchors.

split: true
keys:
  styles:
    default:  # Rough approximation of SA family.
      style: maquette
      switch-type: mx
      skirt-length: 5.75
      top-size: [12.7, 12.7, 6]
      unit-size: [1, 1]
    big:
      style: maquette
      switch-type: mx
      skirt-length: 5.75
      top-size: [12.7, 20, 6]
      unit-size: [1, 1.5]
key-clusters:
  main:
    position:
      anchor: origin
      # To match upstream STL more exactly, raise by the thickness of the
      # bottom plate. The Dactyl-ManuForm was not raised above the ground
      # plane to compensate for a bottom plate, but the DMOTE is.
      offset: [1, 0, 12.9]
    matrix-columns:
    - rows-above-home: 1
      rows-below-home: 1
    - rows-above-home: 1
      rows-below-home: 1
    - rows-above-home: 1
      rows-below-home: 2
    - rows-above-home: 1
      rows-below-home: 2
    - rows-above-home: 1
      rows-below-home: 1
    aliases:
      m00: [0, first]
      m01: [1, first]
      m02: [2, first]
      m03: [3, first]
      back0: [0, last]
      back1: [1, last]
      back2: [2, last]
      right0: [last, 0]
  thumb0:
    position:
      anchor: m00
      offset: [-2, -28, -6]
    matrix-columns:
    - rows-above-home: 0
    - rows-above-home: 0
    aliases:
      thumb-tr: [1, 0]  # Top right.
      thumb-tl: [0, 0]
  thumb1:
    position:
      anchor: thumb-tl
      offset: [3.5, -26, -15]
    matrix-columns:
    - rows-above-home: 1
    - rows-above-home: 1
    aliases:
      thumb-mr: [1, 0]
      thumb-ml: [1, 1]
      thumb-br: [0, 0]
      thumb-bl: [0, 1]
by-key:
  parameters:
    layout:
      matrix:
        separation:
          column: 1.5
          row: 1.2
    wall:
      thickness: 2
      north:
        parallel: 5
        perpendicular: -15
      east:
        parallel: 5
        perpendicular: -15
      south:
        parallel: 5
        perpendicular: -15
      west:
        parallel: 5
        perpendicular: -15
  clusters:
    main:
      parameters:
        layout:
          matrix:
            neutral:
              column: 3
          pitch:
            base: 0
            progressive: 0.25
          roll:
            base: 0.26
            progressive: 0.09
      columns:
        first:
          parameters:
            wall:
              south:
                extent: 0
              west:
                parallel: 8
                perpendicular: -9
        "1":
          parameters:
            wall:
              south:
                extent: 0
        "2":
          parameters:
            layout:
              translation:
                mid: [0, 2.82, -4.5]
            wall:
              west:
                extent: 0
              south:
                extent: 0
        "4":
          parameters:
            layout:
              translation:
                late: [1, -12, 5.64]
    thumb0:
      parameters:
        key-style: big
        layout:
          pitch:
            base: 0.1745
          roll:
            base: -0.4014
          yaw:
            base: 0.1745
        wall:
          north:
            extent: 0
          east:
            extent: 0
          south:
            extent: 0
          west:
            extent: 0
      columns:
        first:
          parameters:
            layout:
              roll:
                intrinsic: 0
              yaw:
                intrinsic: 0
        last:
          parameters:
            layout:
              translation:
                late: [3, -4, -2.2]
    thumb1:
      parameters:
        layout:
          matrix:
            neutral:
              column: 1
            separation:
              column: 1
          pitch:
            base: -0.02
          roll:
            base: -0.59
          yaw:
            base: 0.94
        wall:
          east:
            extent: 0
      columns:
        first:
          parameters:
            # Because of the long walls of the case, full-extent walls cause
            # problems with OpenSCAD’s projections to the ground plane.
            # Therefore, walls on the first column are restricted.
            wall:
              north:
                extent: 4
              south:
                extent: 4
          rows:
            first:
              parameters:
                layout:
                  pitch:
                    intrinsic: -0.26
                  translation:
                    early: [0, -1, 1.7]
            last:
              parameters:
                layout:
                  pitch:
                    intrinsic: -0.05
                  translation:
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

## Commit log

2018-02-05 Major CAD modifications.
    * Improved model parameterization including support for non-rectangular
    key matrices.
    * Improved code reuse and nomenclature.
    * Added an edge-walking algorithm for building the walls.
    * Changed thumb cluster layout to be more concentrated,
    dropping the 1.5U caps and orienting the cluster at a steeper
    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
    [left-4x5.stl, left-4x6.stl, left-5x6.stl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]
2018-02-08 DSA keycaps.
    * Added DSA keycaps as an option, simplifying and generalizing the
    keycap function, which replaces the sa-cap function.
    * Added pre-rotation translation tweaking for individual finger keys.
    * Made the wrist rest hook slightly smaller and less pointy.
    [right-hand.stl, right-wrist.stl]
2018-02-24 Adjustments after first DMOTE prototype.
    * Reworked thumb cluster.
    * Changed the placement of keys to depend on the height where caps are
    at their broadest, instead of the tops of caps, to make separation
    parameters more intuitive and column-specific pitch workable.
    * Narrowed key cap channels.
    * Deepened cutouts for the legs of key switches.
    * Improved parameterization of MCU placement.
    * Simplified MCU holder.
    * Parameterized wall dimensions.
    * Cleaned up walling functions.
    * Added foot plates, but did not restore Short’s holes for threaded
    inserts.
    * Added a back plate for mounting a connecting beam.
    * This feature and the LED housings and foot plates are now
    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
    [right-hand.stl, right-wrist.stl]
2018-03-11 Adjustments after second DMOTE prototype.
    [right-hand.stl, right-wrist.stl]
2018-03-23 Split Clojure code.
    * Distributed code among smaller files for sanity.
    * Added a ‘new-scad’ function for REPL convenience.
2018-03-28 Adjustments after third DMOTE prototype.
    * Added some common ISO metric fastener dimensions.
    * Added nut bosses to the backplate.
    * Added a threaded rod as an alternative means of attaching the
    keyboard to the wrist rest.
    * Revised the wrist rest model for casting the top in silicone.
    * Added an exploded view of the hard base, the soft top and a mould.
    * Further simplification of MCU holder.
    * Further simplification of foot plates.
    * Replaced local deg2rad function with scad-clj’s deg->rad.
    * Replaced ‘α’, ‘effective-α’ and the ‘finger-column-tweak-α’ map with a
    single function, ‘progressive-pitch’.
    * Switched to linear key cutouts at cluster bridge.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
    [right-hand.stl, right-wrist.stl]
2018-03-28 Left-hand-side STLs.
    [left-hand.stl, left-wrist.stl]
2018-04-15 Adjustments after fourth DMOTE prototype.
    * Remodelled the cluster bridge, moving the threaded rod connector to it.
    * Added a second threaded rod connector.
    * Added case-internal nut bosses for threaded rod connectors.
    * Fixed a bug in the edge walking algorithm where one of the
    posts for an inner-corner bracer would extend in the wrong
    direction.
    * Fixed ALPS-style switch depth.
    * Added a secondary lower cutout for each switch, intended for the
    wings of ALPS-style switches.
    * Unified key cutouts and channels into one shape.
    * Added a second, lower vertical bevel to the case wall.
    * Gave the rubber casting mould model a slightly thicker bottom.
    * Minor refactoring.
    * Minor na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
2018-04-16 Split up wrist rest SCAD files.
    * Because some popular slicer software (e.g. Cura) cannot separate
    models sourced from a single STL, the exploded views of the wrist
    model were replaced with a larger number of files.
    * Revised create-models.sh with a Bashism to render all SCAD.
    * Reordered the keyboard-right assembly according to source module.
2018-04-16 New STLs.
    [ambilateral-wrist-insert.stl, ambilateral-wrist-mould.stl, left-hand.stl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]
2018-04-17 Cosmetics.
    * Minor cosmetic changes to the case model.
    * New STLs.
    * Minor linting.
    [left-hand.stl, right-hand.stl]
2018-05-13 Fixes after first DMOTE production print.
    * Added back space for plate-level switch overhang.
    * Added space for wiring along the upper back of the MCU PCB.
    * Separated the positive and negative parts of the RJ9 holder because
    the old solution introduced an infinitesimal crack between the case
    and the socket body in rendering.
    * Changed back plate to be slightly thinner.
2018-05-20 Cleanup.
    * Removed several files.
    * Removed the matrix size patch files, no longer applicable.
    * Removed the Dactyl build guide, which is not up to date for the
    fork and arguably inappropriate for the case source code repo.
    * Removed some old photos in the resources directory.
    * Removed the undocumented ‘tags’ file.
    * Moved parts of the general readme into doc/.
2018-05-23 CLI, YAML.
    * Added a crude CLI.
    * Added support for taking options via YAML instead of Clojure code.
    Thus far this is limited to wrist rest inclusion and foot plates.
    * Added YAML files.
    * Added the project’s first unit tests.
2018-05-26 GNU make.
    * Enabled uberjar compilation.
    * Added a makefile with some variants of the keyboard. This method of
    producing variants is intended to replace the patch files upstream.
    * Revised shell scripts to use make.
    * Updated documentation.
    * Added crude debug printing of active configuration.
    * Fixed a problem compiling the solid wrist rest variant.
2018-05-31 Swapped chain-get for a standard function.
2018-06-02 Configuration validation.
    * Enriched the built-in default configuration with more metadata:
    Help messages. Parsers. Validators.
    * Added user feedback on validation failure, including configuration
    keys superfluous to the specification.
    * Added a self-test mode where the built-in defaults are checked
    against the built-in parsers and validators.
    * Simplified the use of the configuration in the application thanks
    to parsing at init.
    [default.yaml]
2018-06-02 Configuration documentation.
    * Added a function that prints the parameter documentation built into
    the parser as Markdown.
    * Piped the output to options.md.
2018-06-05 Further steps toward generalized key placement.
    * Added the finger cluster matrix to the YAML.
    * Added a cluster-properties function akin to derive-properties for the
    wrist rest.
    * Added a configuration refinement stage where derived properties are
    added to the user configuration, making them accessible through getopt
    in the various modelling functions.
    * Boosting this pattern, local specializations of getopt now use
    partial, and when getopt encounters a missing value, it throws
    an exception instead of exiting the application.
    * Removed functions replaced by the above.
    [default.yaml]
2018-06-06 Finished migrating finger key matrix parameters.
    * Removed the hard-coded finger key matrix parameters.
    Changed all functions necessary to react to YAML instead.
    * Changed enrich-option-metadata to build new accessors along the way.
    * Added better debug output to getopt.
    * Added documentation and test make targets.
2018-06-09 Migrated keycap style.
    * Replaced static keycap style info with numeric parameters.
    * Centralized modelling of keycap channels, removing the
    key-cluster-bridge-cutouts function.
    * Changed default shape of keycap channels into a more layered
    structure.
    * In getopt, added distinction between missing key and value nil.
    * Added a nested structure to the configuration master, with a function
    to fetch the most specific value available.
    * Replaced parsers for double with num.
    * Split unit tests for parameter treatment off from core_test.
    [default.yaml]
2018-06-09 Detailed parsing of foot plate data.
    * Added a parser and validator for the foot-plates configuration.
    * Added support for “last” and “first” keys in that configuration.
    * Fixed tests.
    * Updated dependency on unicode-math to a (local draft) version
    compatible with Clojure 1.9.
    [default.yaml]
2018-06-10 Working nesting section in configuration.
    * Rearranged and added things in the parameter module to parse and
    validate options that may exist at any level of specificity from
    the global to the individual key.
    * Fixed bugs in related stubs.
    * Switched to clj-yaml hoping to get integer keys parsed as integers
    from YAML. Alas it behaves the same as io.forward/yaml.core.
    * Marginally more useful exceptions.
    [default.yaml]
2018-06-10 Migrated neutral pitch row setting.
    * Fixed another bug in parameter nesting.
    * Moved file I/O into core.clj.
    [default.yaml]
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2018-06-10 Migrated progressive roll.
    * Homogenized roll and pitch settings.
    * Made tenting a roll setting.
    * Fixed a regression in the orthographic style.
    * Added YAML files for non-standard column layouts.
    [default.yaml]
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2018-06-11 Visualization.
    * Added a YAML file and make target for full visualization.
    * Fixed keycap visualization.
    [default.yaml]
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2018-06-12 Styling revamp. Migrated mount separation.
    * Migrated mount separation settings to YAML.
    * Removed the “fixed” style as an option, but fixed the general
    algorithm to permit zero progressive pitching and rolling. In
    conjunction with the override system now in place, this obviates
    the fixed style as a discrete option.
    * Refactored the implementation of styling in key placement,
    separating treatment of columns and rows.
    [default.yaml]
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2018-06-14 Migrated thumb key cluster.
    * Replaced static definitions of the thumb cluster with YAML parameters
    on the same pattern as the finger cluster.
    * Added key cluster yaw to accomodate the thumb cluster.
    [default.yaml]
2018-06-16 Migrated walling.
    * Migrated the data inputs to the case walling algorithm to YAML.
    * Broke the wrist rest.
    [default.yaml]
2018-06-17 Migrated case tweak plating.
    * Migrated the entire tweaks module into general functions and YAML.
    * Moved foot plate configuration options into a shared case
    section of the configuration master.
    * Renamed the now-empty tweaks module to “sandbox”, with appropriately
    named no-op functions.
2018-06-17 Key alias support for foot plates.
    * Replaced finger key coordinates in foot plate polygon configuration
    with aliases, thereby adding support for keys outside the finger
    cluster.
    * Removed the configuration details that would have benefited by
    connecting to the thumb cluster, since other elements are in flux.
    [default.yaml, threaded_wrist_rest.yaml]
2018-06-20 Refactored wrist rest plinth.
    * Stopped using the same functions for building the surface of the
    wrist rest as for webbing and walling in key mounts. Replaced these
    with a method using surface heightmaps and chamfering offsets.
    * Moved the functions for producing the curvature of the wrist rest
    into a separate project (dmote-topology).
    * Added a heightmap data file from that separate project.
    * Removed a few other unused functions.
    At time of commit, the support for surface has been accepted
    upstream in scad-clj, but necessary modifications to offset
    have not been submitted for review. Neither’s on maven.
    [default.yaml]
2018-06-24 Universal adoption of key aliases.
    * Converted wrist rest plinth placement to be relative to a key alias.
    * Converted case-side wrist rest fastener placement to be relative to
    a key alias.
    * Made solid wrist rest land bridge a little more flexible for wider
    plinths.
2018-06-24 Renamed outputs.
    * Because wrist rest pads are no longer guaranteed to be ambilateral,
    output file names were changed.
    * Deleted DMOTE v0.1.0 STL files with antiquated names.
    [ambilateral-wrist-insert.stl, ambilateral-wrist-mould.stl, left-hand.stl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]
2018-06-26 Rear housing.
    * Added a squarish hollow block at the far end of the key cluster,
    as an alternative to the furthest row of keys in DMOTE v0.1.0.
    * Unified key webbing functions.
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2018-06-30 Migrated signalling connection.
    * Migrated the sole static parameter for an RJ9 connector to YAML.
    * Generalized the signalling connection socket feature, extracting
    data hard-coded into replaced functions to YAML.
    * Added a feature to optionally place the signalling connection socket
    in relation to the rear housing instead of a key.
    * Removed the peaked roof on the connector housing, without
    replacement.
    [default.yaml]
2018-07-01 Added intrinsic roll and yaw.
    Also added a conditional identity feature to the auxiliaries in
    cluster-place to reduce SCAD complexity.
2018-07-08 Finished migration.
    * Migrated MCU settings.
    * This concludes the migration of all formerly hard-coded parameters
    that existed in the params module itself. There is still some
    hard-coding left in other files.
    * Parameterized the previous style of MCU support, now named stop.
    * Added a lock style of MCU support that should work better with
    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
2018-08-14 Adjustments after first v0.2.0 prototype.
    * Added a setting for extent and direction of hex nut pockets in the
    plinth-side plate for a threaded-style wrist rest.
    * Tweaked thumb and pinky key settings for ergonomy.
    * Tweaked default wrist rest pad heightmap.
2018-08-21 Adjustments after second v0.2.0 prototype.
    * Added a “preview-keycaps” output where the primitive models of the
    caps float in the air for fine tuning.
2018-09-02 Adjustments after third v0.2.0 prototype.
    * Cleaned up the interior of the finger-thumb cluster gap closer.
    * Pitched the first thumb key in the middle column more heavily.
    * Increased thumb cluster yaw to better match angle of thumb coming
    off the wrist rest.
    * Made the plinth-side threaded wrist rest mount slightly more shallow.
2018-09-02 Extra key, bossless mount.
    * Added back a key that is hard to reach. This existed in DMOTE v0.1.0
    but on the opposite side of the case. The new one is on the front,
    extending the thumb cluster.
    * Added a parameter to control the inclusion of nut bosses in the
    case-side mount for a threaded wrist rest.
2018-09-05 New cluster.
    * Added an ‘aux0’ key cluster to get cleaner webbing for the extra
    key near the thumb cluster.
    * Fancier wrist pad heightmap.
    * Taller wrist pad.
    * Triangular-hulled webbing between key mounts.
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2018-10-21 v0.2.0 release. Updated project.clj.
    * Updated dependencies for release of scad-clj 0.5.3.
    * Added a link to a picture of a printed copy of v0.2.0.
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2018-10-28 Cleanup.
    * Fixed the over-use of soft-merge in the previous commit by adding a
    ‘resolve-fn’ key to parameter metadata.
    * Added an explicit System/exit 0, without really knowing why pmap was
    taking so long without it.
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2018-10-28 More elegant default settings.
    * Further updates to YAML, replacing old workarounds with proper use of
    new features.
    [default.yaml]
2018-11-01 Cleanup.
    * Improved use of namespacing.
    * Fixed a leftover reference to alias f2.
    [threaded_wrist_rest.yaml]
2018-11-17 Generic parametrized DFM error function.
    [default.yaml, threaded_wrist_rest.yaml]
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2018-11-24 Body mask adapts to cover bottom plate height.
    This means that a bottom plate will no longer extend the case.
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2018-11-29 Progress with bottom plates.
    Added use of OpenSCAD modules.
    Added features for the installation of bottom plates, including
    the return of heat-set inserts.
    Replaced foot plates in the default configuration with mounts for
    installing the bottom plate. Concomitant changes to wall tweaks.
    Moved the settings for said foot plates into a new configuration file,
    no_bottom.yaml.
    Fixed a regression in into-nook.
    [default.yaml, no_bottom.yaml]
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2019-01-02 Wrist-rest polyhedrons.
    Unified and extended the concept of named anchors, adding a :derived
    section for these to the top level of getopt, and a reckon-feature
    function that acts as a clearing house.
    Separated user parameter parsing from validation, overhauling the
    relationship between the parameter modules.
    Major changes to wrist-rest-related parameters and possibilities.
    Prettier user-facing exceptions on configuration errors.
    Replaced lots of instances of vec on map with mapv.
    Fixed a bug in no_bottom.yaml. Added a corresponding configuration
    fragment for a back plate.
    [default.yaml, no_bottom.yaml, solid.yaml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]
2019-01-05 Cleanup.
    Changed anchoring of the wrist rest to use origin in default.yaml.
    Subtracted plinth-side anchors from the wrist-rest pad.
    More homogeneous use of now generic anchoring features.
    Minor improvements to the setting specs. Removed “origin” as a key
    alias (actually using it as such was already forbidden).
    Corrected documentation.
    [default.yaml]
2019-01-14 Housings for wrist-rest bottom-plate fasteners.
    Added housings. This addition brings harmonization with the case
    code, necessitated by new freedoms. Alas it brings more model code
    back into the core module.
    Added reorientation of the plinth pad model for ease of printing,
    generalized from what already existed for the mould.
    Fixed a bug that caused wrist-rest bottom-plate fasteners to use the
    sprue inset. Fixed a leftover highlight.
    Adjusted settings and parameter descriptions accordingly.
    [default.yaml]
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2019-03-23 Cleaner rear housing functions.
    Fixed a bug drawing the bottom plate underneath the rear housing.
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2019-03-24 Dynamic outputs.
    Added two model outputs for each non-maquette style of keycap in the
    configuration. Renamed the “preview-keycap” output to
    “preview-keycap-clusters” to prevent confusion with the new printable
    outputs.
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2019-04-12 Bottom-plate intersection with wall.
    This includes adding a workaround for a pesky behaviour in OpenSCAD:
    Moving the polygon representing the floor of the rear housing a tiny
    distance to prevent a broken mesh under particular circumstances
    noted in a comment.
2019-06-01 Keycap supports for printing.
    This replaces the earlier solution of providing both upright and
    upside-down outputs for each style of keycap.
2019-06-05 Perfunctory wrist-rest fixes.
    Patched obvious loss of functionality in wrist-rest configuration files
    without actually printing or using them as configured.
    [default.yaml, threaded_caseside.yaml, threaded_mutual.yaml]
2019-06-08 M4 bottom-plate fasteners.
    Also corrected wrist-rest anchor placement and added a vertical offset
    for such anchors with respect to bottom plates.
    [default.yaml]
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2019-06-09 Deprivileged the DMOTE as a build target.
    Broke up default.yaml, moving most of it into a subdirectory
    beside a separate directory for the Dactyl-ManuForm, and removing
    the code’s reference to it. This change is intended to simplify
    future diversity.
    [base.yaml, no_bottom.yaml, threaded_caseside.yaml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]
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2019-06-19 Windows file system compatibility.
    Renamed a file (from `aux` to `auxf`) to work around restrictions
    inherited from MS DOS into current versions of Windows. Fixes #13.
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2019-07-21 Oblong key-mount support. Lower mounts.
    The Dactyl-ManuForm, DMOTE and macropad configurations have all been
    raised to compensate.
    The Dactyl-ManuForm configuration also received a perfunctory fix for
    bad walls and broken bottom plating.
    [base.yaml]
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2019-10-28 Lets split: adding result STL file for visualization
    [left_demo.stl]
